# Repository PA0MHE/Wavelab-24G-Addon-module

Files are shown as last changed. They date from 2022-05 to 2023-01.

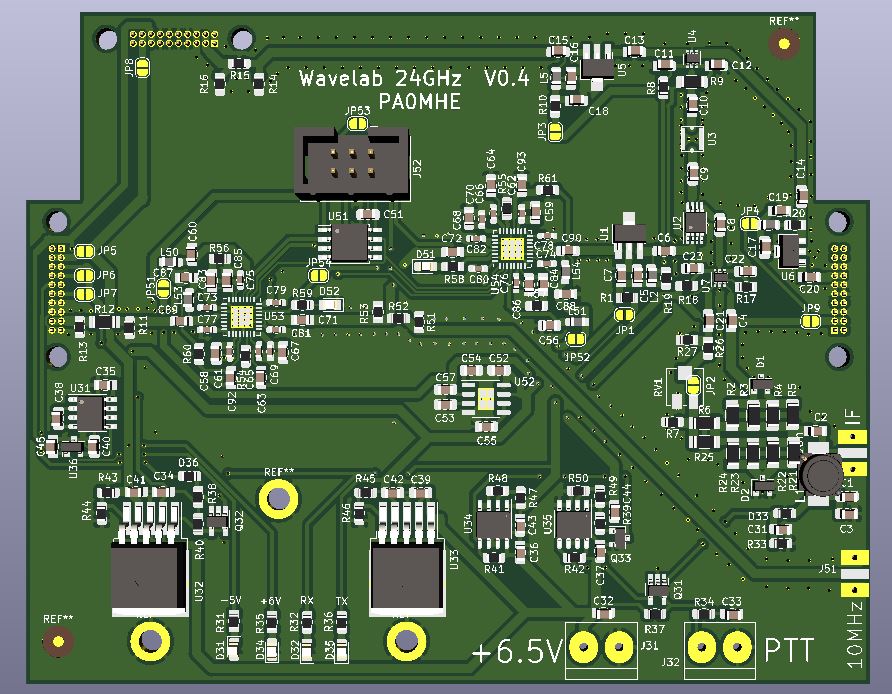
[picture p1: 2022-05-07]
Wavelab24GHzAddon3D_Top_V04.JPG

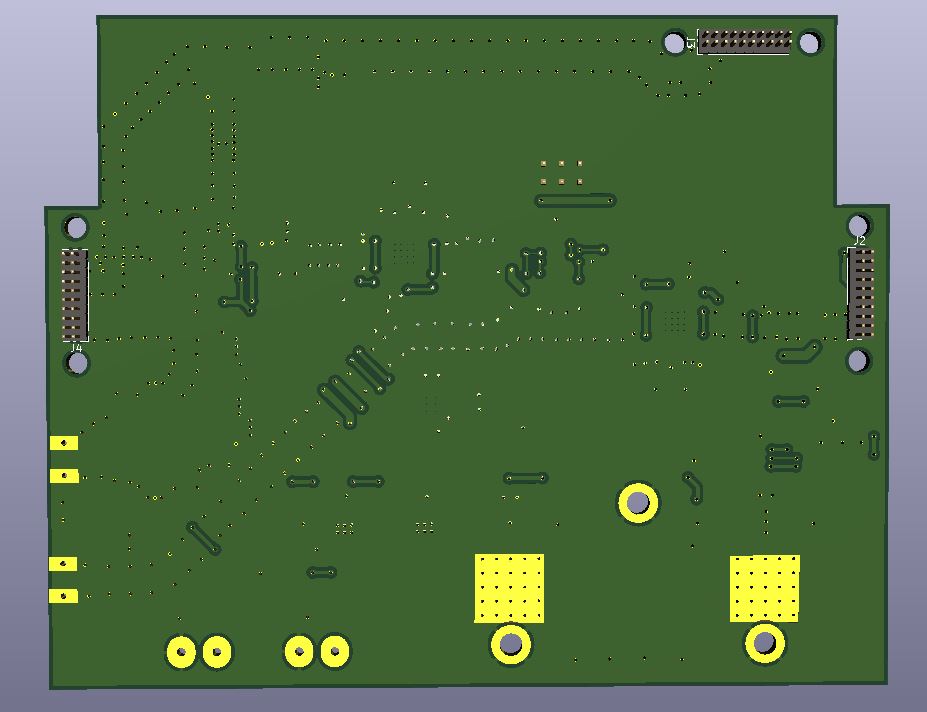
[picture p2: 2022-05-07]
Wavelab24GHzAddon3D_Bottom_v04.JPG

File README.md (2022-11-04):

# Wavelab addon module

Can be used as addon module for the Wavelab 23X1008XP module, which was available during the 2021-2022 timeframe on www.ebay.pl seller:bisonelectronics-sp2jyr
The module converts the first-IF 2364MHz to 432MHz (or 144MHz) , it als generates the required first LO of 1807MHz. It also generates all required DC value, such as 6.5V, +5V, -5V, also the required RX-TX switching is provided. 
The module requires a 10MHz reference signal, it has to be supplied with 7.5V DC. 

# Key components:

HMC213B
2x AS179-92LF
LFB2H2G45SG7C093
2x ADF4351
2x MIC29302
2x BD50HC5MEFJ
ADM7150/1  
ATtiny85-20S  

# PCB

Gerber files are included, PCB's can be ordered at JCL PCB substrate thickness is 0.8mm 

73's Maarten PA0MHE

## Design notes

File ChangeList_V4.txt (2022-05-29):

Complete new PSU circuit
Removed both buck converters --> LDO's MIC29302 and  BD50HC5MEFJ
Input voltage now 6.5V

ATTiny85 U51: connected +3V3A
Pin1 U51 ATTiny85 disconnected from MUXOUT pin30 U54, pin 5 U51 from MUXOUT pin30 U53

Lib element Q31 and Q32 EMG1 changed to TO25-5

Extra 68ohm R19 parallel L2 (drain SBB3089) to avoid oscillations
Footprint both zenerdiode changed to 0805

Add extra 4K7 pullup resistor R37 from PTT to 6.5V
Zener D36 changed to 5V1.
ICSP J52 connector footprint changed to SMD

To get more RX gain, optional U6 PGA103 can be replaced by MGA85675, extra R20 in series drain

Modified IF input can now handle 5W

To improve the -5V stabilization:
- Change the supply voltage from 6.5V into 7.5V. But now a small heatsink is required for U32 and U33
- Change C38 and C40 into 22uF e.g. 22uF 10V 0805 Mouser 81-GRM21BR61A226ME1L

To better get +6V on "+6 TX":
Change R44 from 200E into 180E

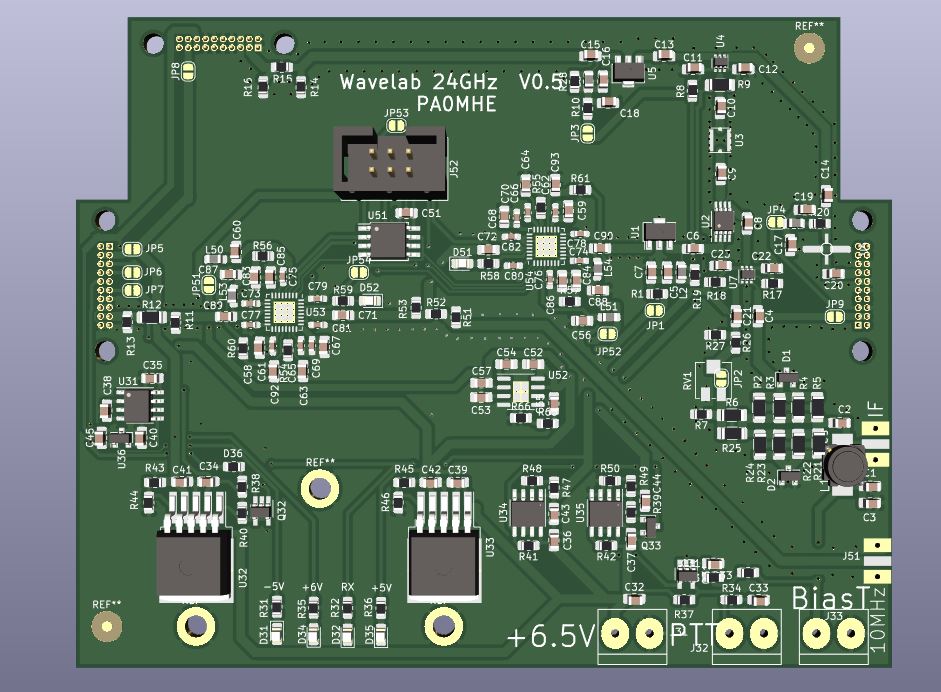
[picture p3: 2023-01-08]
V5_documentation/Wavelab24GHzAddon3D_Top_v05.JPG

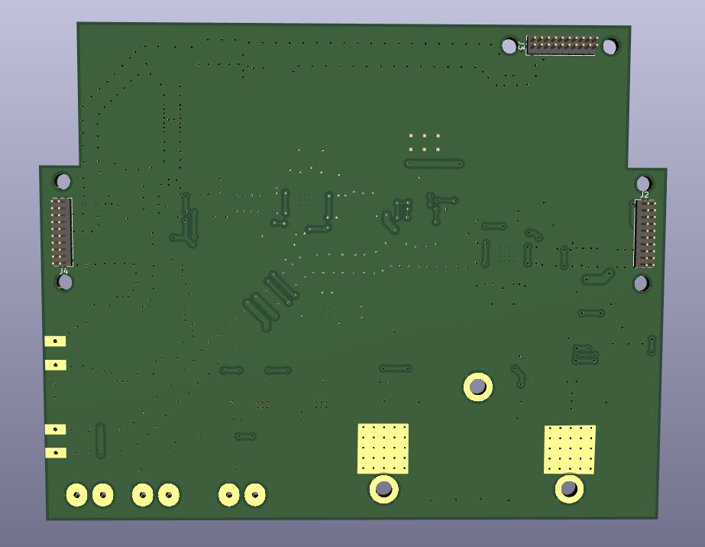
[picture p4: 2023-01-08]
V5_documentation/Wavelab24GHzAddon3D_Bottom_v05.JPG

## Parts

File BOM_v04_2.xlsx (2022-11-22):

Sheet: BOM
Source: | D:\Users\Maarten\Documents\Kicad\WaveLab24GHz\WaveLab24GHz.sch
Date: | 2022-03-28 20:42
Tool: | Eeschema (5.1.7)-1
Component Count: | 200
Ref | Value | Alternative | Footprint | Datasheet | Manufacturer | Vendor
C1 | res 1n |  | Capacitor_SMD:C_0805_2012Metric_Pad1.18x1.45mm_HandSolder | ~
C2 | 220p |  | Capacitor_SMD:C_0805_2012Metric_Pad1.18x1.45mm_HandSolder | ~
C3 | res 220p |  | Capacitor_SMD:C_0805_2012Metric_Pad1.18x1.45mm_HandSolder | ~
C4 | 220p |  | Capacitor_SMD:C_0805_2012Metric_Pad1.18x1.45mm_HandSolder | ~
C5 | 22p |  | Capacitor_SMD:C_0805_2012Metric_Pad1.18x1.45mm_HandSolder | ~
C6 | 1n |  | Capacitor_SMD:C_0805_2012Metric_Pad1.18x1.45mm_HandSolder | ~
C7 | 1nF |  | Capacitor_SMD:C_0805_2012Metric_Pad1.18x1.45mm_HandSolder | ~
C8 | 220p |  | Capacitor_SMD:C_0805_2012Metric_Pad1.18x1.45mm_HandSolder | ~
C9 | 10p |  | Capacitor_SMD:C_0805_2012Metric_Pad1.18x1.45mm_HandSolder | ~
C10 | 10p |  | Capacitor_SMD:C_0805_2012Metric_Pad1.18x1.45mm_HandSolder | ~
C11 | 10p |  | Capacitor_SMD:C_0805_2012Metric_Pad1.18x1.45mm_HandSolder | ~
C12 | 10p |  | Capacitor_SMD:C_0805_2012Metric_Pad1.18x1.45mm_HandSolder | ~
C13 | 10p |  | Capacitor_SMD:C_0805_2012Metric_Pad1.18x1.45mm_HandSolder | ~
C14 | 1n |  | Capacitor_SMD:C_0805_2012Metric_Pad1.18x1.45mm_HandSolder | ~
C15 | 1n |  | Capacitor_SMD:C_0805_2012Metric_Pad1.18x1.45mm_HandSolder | ~
C16 | 10p |  | Capacitor_SMD:C_0805_2012Metric_Pad1.18x1.45mm_HandSolder | ~
C17 | 10p |  | Capacitor_SMD:C_0805_2012Metric_Pad1.18x1.45mm_HandSolder | ~
C18 | 1nF |  | Capacitor_SMD:C_0805_2012Metric_Pad1.18x1.45mm_HandSolder | ~
C19 | 1nF |  | Capacitor_SMD:C_0805_2012Metric_Pad1.18x1.45mm_HandSolder | ~
C20 | 10p |  | Capacitor_SMD:C_0805_2012Metric_Pad1.18x1.45mm_HandSolder | ~
C21 | 220p |  | Capacitor_SMD:C_0805_2012Metric_Pad1.18x1.45mm_HandSolder | ~
C22 | 220p |  | Capacitor_SMD:C_0805_2012Metric_Pad1.18x1.45mm_HandSolder | ~
C23 | 220p |  | Capacitor_SMD:C_0805_2012Metric_Pad1.18x1.45mm_HandSolder | ~
C31 | res |  | Capacitor_SMD:C_0805_2012Metric_Pad1.18x1.45mm_HandSolder | ~
C32 | 100p |  | Capacitor_SMD:C_0805_2012Metric_Pad1.18x1.45mm_HandSolder | ~
C33 | 100p |  | Capacitor_SMD:C_0805_2012Metric_Pad1.18x1.45mm_HandSolder | ~
C34 | 10u |  | Capacitor_SMD:C_0805_2012Metric_Pad1.18x1.45mm_HandSolder | ~
C35 | 10u |  | Capacitor_SMD:C_0805_2012Metric_Pad1.18x1.45mm_HandSolder | ~
C36 | 10u |  | Capacitor_SMD:C_0805_2012Metric_Pad1.18x1.45mm_HandSolder | ~
C37 | 10u |  | Capacitor_SMD:C_0805_2012Metric_Pad1.18x1.45mm_HandSolder | ~
C38 | 10u |  | Capacitor_SMD:C_0805_2012Metric_Pad1.18x1.45mm_HandSolder | ~
C39 | 10u |  | Capacitor_SMD:C_0805_2012Metric_Pad1.18x1.45mm_HandSolder | ~
C40 | 10u |  | Capacitor_SMD:C_0805_2012Metric_Pad1.18x1.45mm_HandSolder | ~
C41 | 10u |  | Capacitor_SMD:C_0805_2012Metric_Pad1.18x1.45mm_HandSolder | ~
C42 | 10u |  | Capacitor_SMD:C_0805_2012Metric_Pad1.18x1.45mm_HandSolder | ~
C43 | 10u |  | Capacitor_SMD:C_0805_2012Metric_Pad1.18x1.45mm_HandSolder | ~
C44 | 10u |  | Capacitor_SMD:C_0805_2012Metric_Pad1.18x1.45mm_HandSolder | ~
C45 | 10u |  | Capacitor_SMD:C_0805_2012Metric_Pad1.18x1.45mm_HandSolder | ~
C51 | 100n |  | Capacitor_SMD:C_0805_2012Metric_Pad1.18x1.45mm_HandSolder | ~
C52 | 10u |  | Capacitor_SMD:C_0805_2012Metric_Pad1.18x1.45mm_HandSolder | ~
C53 | 1u |  | Capacitor_SMD:C_0805_2012Metric_Pad1.18x1.45mm_HandSolder | ~
C54 | 10u |  | Capacitor_SMD:C_0805_2012Metric_Pad1.18x1.45mm_HandSolder | ~
C55 | 1u |  | Capacitor_SMD:C_0805_2012Metric_Pad1.18x1.45mm_HandSolder | ~
C56 | 10u |  | Capacitor_SMD:C_0805_2012Metric_Pad1.18x1.45mm_HandSolder | ~
C57 | 10u |  | Capacitor_SMD:C_0805_2012Metric_Pad1.18x1.45mm_HandSolder | ~
C58 | 100n |  | Capacitor_SMD:C_0805_2012Metric_Pad1.18x1.45mm_HandSolder | ~
C59 | 100n |  | Capacitor_SMD:C_0805_2012Metric_Pad1.18x1.45mm_HandSolder | ~
C60 | 10u |  | Capacitor_SMD:C_0805_2012Metric_Pad1.18x1.45mm_HandSolder | ~
C61 | 10p |  | Capacitor_SMD:C_0603_1608Metric_Pad1.08x0.95mm_HandSolder | ~
C62 | 10p |  | Capacitor_SMD:C_0603_1608Metric_Pad1.08x0.95mm_HandSolder | ~
C63 | 100n |  | Capacitor_SMD:C_0805_2012Metric_Pad1.18x1.45mm_HandSolder | ~
C64 | 100n |  | Capacitor_SMD:C_0805_2012Metric_Pad1.18x1.45mm_HandSolder | ~
C65 | 10p |  | Capacitor_SMD:C_0603_1608Metric_Pad1.08x0.95mm_HandSolder | ~
C66 | 10p |  | Capacitor_SMD:C_0603_1608Metric_Pad1.08x0.95mm_HandSolder | ~
C67 | 100n |  | Capacitor_SMD:C_0805_2012Metric_Pad1.18x1.45mm_HandSolder | ~
C68 | 100n |  | Capacitor_SMD:C_0805_2012Metric_Pad1.18x1.45mm_HandSolder | ~
C69 | 10p |  | Capacitor_SMD:C_0603_1608Metric_Pad1.08x0.95mm_HandSolder | ~
C70 | 10p |  | Capacitor_SMD:C_0603_1608Metric_Pad1.08x0.95mm_HandSolder | ~
C71 | 1n |  | Capacitor_SMD:C_0805_2012Metric_Pad1.18x1.45mm_HandSolder | ~
C72 | 1n |  | Capacitor_SMD:C_0805_2012Metric_Pad1.18x1.45mm_HandSolder | ~
C73 | 100p |  | Capacitor_SMD:C_0603_1608Metric_Pad1.08x0.95mm_HandSolder | ~
C74 | 100p |  | Capacitor_SMD:C_0603_1608Metric_Pad1.08x0.95mm_HandSolder | ~
C75 | 100p |  | Capacitor_SMD:C_0603_1608Metric_Pad1.08x0.95mm_HandSolder | ~
C76 | 100p |  | Capacitor_SMD:C_0603_1608Metric_Pad1.08x0.95mm_HandSolder | ~
C77 | 100p |  | Capacitor_SMD:C_0603_1608Metric_Pad1.08x0.95mm_HandSolder | ~
C78 | 100p |  | Capacitor_SMD:C_0603_1608Metric_Pad1.08x0.95mm_HandSolder | ~
C79 | 100p |  | Capacitor_SMD:C_0603_1608Metric_Pad1.08x0.95mm_HandSolder | ~
C80 | 100p |  | Capacitor_SMD:C_0603_1608Metric_Pad1.08x0.95mm_HandSolder | ~
C81 | 100p |  | Capacitor_SMD:C_0603_1608Metric_Pad1.08x0.95mm_HandSolder | ~
C82 | 100p |  | Capacitor_SMD:C_0603_1608Metric_Pad1.08x0.95mm_HandSolder | ~
C83 | 47n |  | Capacitor_SMD:C_0805_2012Metric_Pad1.18x1.45mm_HandSolder | ~
C84 | 47n |  | Capacitor_SMD:C_0805_2012Metric_Pad1.18x1.45mm_HandSolder | ~
C85 | 3n3 |  | Capacitor_SMD:C_0805_2012Metric_Pad1.18x1.45mm_HandSolder | ~
C86 | 3n3 |  | Capacitor_SMD:C_0805_2012Metric_Pad1.18x1.45mm_HandSolder | ~
C87 | 100p |  | Capacitor_SMD:C_0805_2012Metric_Pad1.18x1.45mm_HandSolder | ~
C88 | 100p |  | Capacitor_SMD:C_0805_2012Metric_Pad1.18x1.45mm_HandSolder | ~
C89 | 22p |  | Capacitor_SMD:C_0805_2012Metric_Pad1.18x1.45mm_HandSolder | ~
C90 | 10p |  | Capacitor_SMD:C_0805_2012Metric_Pad1.18x1.45mm_HandSolder | ~
C92 | 470p |  | Capacitor_SMD:C_0805_2012Metric_Pad1.18x1.45mm_HandSolder | ~
C93 | 470p |  | Capacitor_SMD:C_0805_2012Metric_Pad1.18x1.45mm_HandSolder | ~
D1 | BAV99 |  | Package_TO_SOT_SMD:SOT-23 | https://assets.nexperia.com/documents/data-sheet/BAV99_SER.pdf
D2 | opt |  | Package_TO_SOT_SMD:SOT-23 | https://assets.nexperia.com/documents/data-sheet/BAV99_SER.pdf
D31 | LED |  | LED_SMD:LED_0805_2012Metric_Pad1.15x1.40mm_HandSolder | ~
D32 | LED |  | LED_SMD:LED_0805_2012Metric_Pad1.15x1.40mm_HandSolder | ~
D33 | res |  | Resistor_SMD:R_0805_2012Metric_Pad1.20x1.40mm_HandSolder | ~
D34 | LED |  | LED_SMD:LED_0805_2012Metric_Pad1.15x1.40mm_HandSolder | ~
D35 | LED |  | LED_SMD:LED_0805_2012Metric_Pad1.15x1.40mm_HandSolder | ~
D36 | 5V1 |  | Resistor_SMD:R_0805_2012Metric_Pad1.20x1.40mm_HandSolder | ~
D51 | LED |  | LED_SMD:LED_0805_2012Metric_Pad1.15x1.40mm_HandSolder | ~
D52 | LED |  | LED_SMD:LED_0805_2012Metric_Pad1.15x1.40mm_HandSolder | ~
J1 | Conn_Coaxial |  | my_library:SMA_side_PCB | ~
J2 | Conn_LO |  | my_library:PinHeader_24GHzl | ~
J3 | Conn_TXIF |  | my_library:PinHeader_24GHzl | ~
J4 | Conn_RXIF |  | my_library:PinHeader_24GHzl | ~
J31 | 6.5V |  | my_library:KF301-2P | ~
J32 | PTT |  | my_library:KF301-2P | ~
J33 | Bias-T |  | my_library:KF301-2P | ~
J51 | SMA 10MHz |  | my_library:SMA_side_PCB | ~
J52 | ICSP |  | my_library:IDC-Header_2x03_P2.54mm_SMD | ~
JP1 | S |  | Jumper:SolderJumper-2_P1.3mm_Open_RoundedPad1.0x1.5mm | ~
JP2 | S |  | Jumper:SolderJumper-2_P1.3mm_Open_RoundedPad1.0x1.5mm | ~
JP3 | S |  | Jumper:SolderJumper-2_P1.3mm_Open_RoundedPad1.0x1.5mm | ~
JP4 | S |  | Jumper:SolderJumper-2_P1.3mm_Open_RoundedPad1.0x1.5mm | ~
JP5 | S |  | Jumper:SolderJumper-2_P1.3mm_Open_RoundedPad1.0x1.5mm | ~
JP6 | S |  | Jumper:SolderJumper-2_P1.3mm_Open_RoundedPad1.0x1.5mm | ~
JP7 | S |  | Jumper:SolderJumper-2_P1.3mm_Open_RoundedPad1.0x1.5mm | ~
JP8 | S |  | Jumper:SolderJumper-2_P1.3mm_Open_RoundedPad1.0x1.5mm | ~
JP9 | S |  | Jumper:SolderJumper-2_P1.3mm_Open_RoundedPad1.0x1.5mm | ~
JP51 | S |  | Jumper:SolderJumper-2_P1.3mm_Open_RoundedPad1.0x1.5mm | ~
JP52 | S |  | Jumper:SolderJumper-2_P1.3mm_Open_RoundedPad1.0x1.5mm | ~
JP53 | S |  | Jumper:SolderJumper-2_P1.3mm_Open_RoundedPad1.0x1.5mm | ~
JP54 | S |  | Jumper:SolderJumper-2_P1.3mm_Open_RoundedPad1.0x1.5mm | ~
L1 | res |  | my_library:AirCoilSMD | ~
L2 | 33n |  | Inductor_SMD:L_0805_2012Metric_Pad1.15x1.40mm_HandSolder | ~
L5 | 33n |  | Inductor_SMD:L_0805_2012Metric_Pad1.15x1.40mm_HandSolder | ~
L6 | 33n |  | Inductor_SMD:L_0805_2012Metric_Pad1.15x1.40mm_HandSolder | ~
L50 | 100u |  | Inductor_SMD:L_0805_2012Metric_Pad1.05x1.20mm_HandSolder | ~
L51 | 100u |  | Inductor_SMD:L_0805_2012Metric_Pad1.05x1.20mm_HandSolder | ~
L53 | 3n9 |  | Inductor_SMD:L_0805_2012Metric_Pad1.05x1.20mm_HandSolder | ~
L54 | 3n9 |  | Inductor_SMD:L_0805_2012Metric_Pad1.05x1.20mm_HandSolder | ~
Q31 | FMG1 |  | Package_TO_SOT_SMD:SOT-23-5_HandSoldering
Q32 | FMG1 |  | Package_TO_SOT_SMD:SOT-23-5_HandSoldering
Q33 | BC849 |  | Package_TO_SOT_SMD:SOT-23 | http://www.infineon.com/dgdl/Infineon-BC847SERIES_BC848SERIES_BC849SERIES_BC850SERIES-DS-v01_01-en.pdf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
R1 | 12R |  | Resistor_SMD:R_0805_2012Metric_Pad1.20x1.40mm_HandSolder | ~
R2 | 220R |  | Resistor_SMD:R_1206_3216Metric_Pad1.30x1.75mm_HandSolder | ~
R3 | 220R |  | Resistor_SMD:R_1206_3216Metric_Pad1.30x1.75mm_HandSolder | ~
R4 | 220R |  | Resistor_SMD:R_1206_3216Metric_Pad1.30x1.75mm_HandSolder | ~
R5 | 220R |  | Resistor_SMD:R_1206_3216Metric_Pad1.30x1.75mm_HandSolder | ~
R6 | res |  | Resistor_SMD:R_1206_3216Metric_Pad1.30x1.75mm_HandSolder | ~
R7 | res |  | Resistor_SMD:R_0805_2012Metric_Pad1.20x1.40mm_HandSolder | ~
R8 | 1K |  | Resistor_SMD:R_0805_2012Metric_Pad1.20x1.40mm_HandSolder | ~
R9 | 1K |  | Resistor_SMD:R_1206_3216Metric_Pad1.30x1.75mm_HandSolder | ~
R10 | 12R |  | Resistor_SMD:R_0805_2012Metric_Pad1.20x1.40mm_HandSolder | ~
R11 | res |  | Resistor_SMD:R_0805_2012Metric_Pad1.20x1.40mm_HandSolder | ~
R12 | 0R |  | Resistor_SMD:R_1206_3216Metric_Pad1.30x1.75mm_HandSolder | ~
R13 | res |  | Resistor_SMD:R_0805_2012Metric_Pad1.20x1.40mm_HandSolder | ~
R14 | res |  | Resistor_SMD:R_0805_2012Metric_Pad1.20x1.40mm_HandSolder | ~
R15 | 0R |  | Resistor_SMD:R_0805_2012Metric_Pad1.20x1.40mm_HandSolder | ~
R16 | res |  | Resistor_SMD:R_0805_2012Metric_Pad1.20x1.40mm_HandSolder | ~
R17 | 1K |  | Resistor_SMD:R_0805_2012Metric_Pad1.20x1.40mm_HandSolder | ~
R18 | 1K |  | Resistor_SMD:R_0805_2012Metric_Pad1.20x1.40mm_HandSolder | ~
R19 | 68R |  | Resistor_SMD:R_0805_2012Metric_Pad1.20x1.40mm_HandSolder | ~
R20 | 10R |  | Resistor_SMD:R_0805_2012Metric_Pad1.20x1.40mm_HandSolder | ~
R21 | res |  | Resistor_SMD:R_1206_3216Metric_Pad1.30x1.75mm_HandSolder | ~
R22 | res |  | Resistor_SMD:R_1206_3216Metric_Pad1.30x1.75mm_HandSolder | ~
R23 | res |  | Resistor_SMD:R_1206_3216Metric_Pad1.30x1.75mm_HandSolder | ~
R24 | res |  | Resistor_SMD:R_1206_3216Metric_Pad1.30x1.75mm_HandSolder | ~
R25 | 220R |  | Resistor_SMD:R_1206_3216Metric_Pad1.30x1.75mm_HandSolder | ~
R26 | 0R |  | Resistor_SMD:R_0805_2012Metric_Pad1.20x1.40mm_HandSolder | ~
R27 | 51R |  | Resistor_SMD:R_0805_2012Metric_Pad1.20x1.40mm_HandSolder | ~
R28 | 150R |  | Resistor_SMD:R_0805_2012Metric_Pad1.20x1.40mm_HandSolder | ~
R31 | 2K2 |  | Resistor_SMD:R_0805_2012Metric_Pad1.20x1.40mm_HandSolder | ~
R32 | 2K2 |  | Resistor_SMD:R_0805_2012Metric_Pad1.20x1.40mm_HandSolder | ~
R33 | res |  | Resistor_SMD:R_0805_2012Metric_Pad1.20x1.40mm_HandSolder | ~
R34 | 100R |  | Resistor_SMD:R_0805_2012Metric_Pad1.20x1.40mm_HandSolder | ~
R35 | 2K2 |  | Resistor_SMD:R_0805_2012Metric_Pad1.20x1.40mm_HandSolder | ~
R36 | 2K2 |  | Resistor_SMD:R_0805_2012Metric_Pad1.20x1.40mm_HandSolder | ~
R37 | 4K7 |  | Resistor_SMD:R_0805_2012Metric_Pad1.20x1.40mm_HandSolder | ~
R38 | 47K |  | Resistor_SMD:R_0805_2012Metric_Pad1.20x1.40mm_HandSolder | ~
R39 | 22K |  | Resistor_SMD:R_0805_2012Metric_Pad1.20x1.40mm_HandSolder | ~
R40 | 47K |  | Resistor_SMD:R_0805_2012Metric_Pad1.20x1.40mm_HandSolder | ~
R41 | 47K |  | Resistor_SMD:R_0805_2012Metric_Pad1.20x1.40mm_HandSolder | ~
R42 | 47K |  | Resistor_SMD:R_0805_2012Metric_Pad1.20x1.40mm_HandSolder | ~
R43 | 750R |  | Resistor_SMD:R_0805_2012Metric_Pad1.20x1.40mm_HandSolder | ~
R44 | 200R |  | Resistor_SMD:R_0805_2012Metric_Pad1.20x1.40mm_HandSolder | ~
R45 | 620R |  | Resistor_SMD:R_0805_2012Metric_Pad1.20x1.40mm_HandSolder | ~
R46 | 200R |  | Resistor_SMD:R_0805_2012Metric_Pad1.20x1.40mm_HandSolder | ~
R47 | 0R |  | Resistor_SMD:R_0805_2012Metric_Pad1.20x1.40mm_HandSolder | ~
R48 | res |  | Resistor_SMD:R_0805_2012Metric_Pad1.20x1.40mm_HandSolder | ~
R49 | 0R |  | Resistor_SMD:R_0805_2012Metric_Pad1.20x1.40mm_HandSolder | ~
R50 | res |  | Resistor_SMD:R_0805_2012Metric_Pad1.20x1.40mm_HandSolder | ~
R51 | 62R |  | Resistor_SMD:R_0805_2012Metric_Pad1.20x1.40mm_HandSolder | ~
R52 | 270R |  | Resistor_SMD:R_0805_2012Metric_Pad1.20x1.40mm_HandSolder | ~
R53 | 62R |  | Resistor_SMD:R_0805_2012Metric_Pad1.20x1.40mm_HandSolder | ~
R54 | 5K1 |  | Resistor_SMD:R_0805_2012Metric_Pad1.20x1.40mm_HandSolder | ~
R55 | 5K1 |  | Resistor_SMD:R_0805_2012Metric_Pad1.20x1.40mm_HandSolder | ~
R56 | 470R |  | Resistor_SMD:R_0805_2012Metric_Pad1.20x1.40mm_HandSolder | ~
R57 | 470R |  | Resistor_SMD:R_0805_2012Metric_Pad1.20x1.40mm_HandSolder | ~
R58 | 2K2 |  | Resistor_SMD:R_0805_2012Metric_Pad1.20x1.40mm_HandSolder | ~
R59 | 2K2 |  | Resistor_SMD:R_0805_2012Metric_Pad1.20x1.40mm_HandSolder | ~
R60 | 2K2 |  | Resistor_SMD:R_0805_2012Metric_Pad1.20x1.40mm_HandSolder | ~
R61 | 2K2 |  | Resistor_SMD:R_0805_2012Metric_Pad1.20x1.40mm_HandSolder | ~
RV1 | res |  | Potentiometer_SMD:Potentiometer_Vishay_TS53YJ_Vertical | ~
U1 | SBB3089Z |  | Package_TO_SOT_SMD:SOT-89-3_Handsoldering
U2 | HMC213B |  | Package_SO:MSOP-8_3x3mm_P0.65mm | https://www.analog.com/media/en/technical-documentation/data-sheets/hmc213B.pdf
U3 | LFB2H2G45SG7C093 |  | my_library:LFSN25N
U4 | AS179-92LF | SKY13343-92LF | Package_TO_SOT_SMD:SOT-363_SC-70-6 | http://www.skyworksinc.com/uploads/documents/AS179_92LF_200176H.pdf
U5 | SBB3089Z |  | Package_TO_SOT_SMD:SOT-89-3_Handsoldering
U6 | MGA-86576 |  | Package_TO_SOT_SMD:SOT-89-3 | https://www.minicircuits.com/pdfs/PGA-103+.pdf
U7 | AS179-92LF | SKY13343-92LF | Package_TO_SOT_SMD:SOT-363_SC-70-6 | http://www.skyworksinc.com/uploads/documents/AS179_92LF_200176H.pdf
U31 | ICL7662 |  | Package_SO:SOIC-8_3.9x4.9mm_P1.27mm | http://ww1.microchip.com/downloads/en/DeviceDoc/21469a.pdf
U32 | MIC29302 | LP3876ESX-ADJ | Package_TO_SOT_SMD:TO-263-5_TabPin6
U33 | MIC29302 | LP3876ESX-ADJ | Package_TO_SOT_SMD:TO-263-5_TabPin6
U34 | BD50HC5MEFJ |  | Package_SO:HTSOP-8-1EP_3.9x4.9mm_P1.27mm_EP2.4x3.2mm | http://rohmfs.rohm.com/en/products/databook/datasheet/ic/power/linear_regulator/bdxxga5wefj-e.pdf
U35 | BD50HC5MEFJ |  | Package_SO:HTSOP-8-1EP_3.9x4.9mm_P1.27mm_EP2.4x3.2mm | http://rohmfs.rohm.com/en/products/databook/datasheet/ic/power/linear_regulator/bdxxga5wefj-e.pdf
U36 | TC5950 |  | Package_TO_SOT_SMD:SOT-23
U51 | ATtiny85-20SU |  | Package_SO:SOIJ-8_5.3x5.3mm_P1.27mm | http://ww1.microchip.com/downloads/en/DeviceDoc/atmel-2586-avr-8-bit-microcontroller-attiny25-attiny45-attiny85_datasheet.pdf
U52 | ADM7150DZ-3V3 | ADM7151ARDZ-04-07 | Package_SO:SOIC-8-1EP_3.9x4.9mm_P1.27mm_EP2.29x3mm_ThermalVias
U53 | ADF4351 |  | Package_CSP:LFCSP-32-1EP_5x5mm_P0.5mm_EP3.1x3.1mm_ThermalVias | https://www.analog.com/media/en/technical-documentation/data-sheets/ADF4351.pdf
U54 | ADF4351 |  | Package_CSP:LFCSP-32-1EP_5x5mm_P0.5mm_EP3.1x3.1mm_ThermalVias | https://www.analog.com/media/en/technical-documentation/data-sheets/ADF4351.pdf

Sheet: Bom_grouped
Reference | Quantity | Value | Footprint | Datasheet
C1 | 1 | res 1n | Capacitor_SMD:C_0805_2012Metric_Pad1.18x1.45mm_HandSolder | ~
C9 C10 C11 C12 C13 C16 C17 C20 C90 | 9 | 10p | Capacitor_SMD:C_0805_2012Metric_Pad1.18x1.45mm_HandSolder | ~
C3 | 1 | res 220p | Capacitor_SMD:C_0805_2012Metric_Pad1.18x1.45mm_HandSolder | ~
C31 | 1 | res | Capacitor_SMD:C_0805_2012Metric_Pad1.18x1.45mm_HandSolder | ~
C32 C33 C87 C88 | 4 | 100p | Capacitor_SMD:C_0805_2012Metric_Pad1.18x1.45mm_HandSolder | ~
C34 C35 C36 C37 C38 C39 C40 C41 C42 C43 C44 C45 C52 C54 C56 C57 C60 | 17 | 10u | Capacitor_SMD:C_0805_2012Metric_Pad1.18x1.45mm_HandSolder | ~
C5 C89 | 2 | 22p | Capacitor_SMD:C_0805_2012Metric_Pad1.18x1.45mm_HandSolder | ~
C53 C55 | 2 | 1u | Capacitor_SMD:C_0805_2012Metric_Pad1.18x1.45mm_HandSolder | ~
C51 C58 C59 C63 C64 C67 C68 | 7 | 100n | Capacitor_SMD:C_0805_2012Metric_Pad1.18x1.45mm_HandSolder | ~
C6 C14 C15 C71 C72 | 5 | 1n | Capacitor_SMD:C_0805_2012Metric_Pad1.18x1.45mm_HandSolder | ~
C61 C62 C65 C66 C69 C70 | 6 | 10p | Capacitor_SMD:C_0603_1608Metric_Pad1.08x0.95mm_HandSolder | ~
C7 C18 C19 | 3 | 1nF | Capacitor_SMD:C_0805_2012Metric_Pad1.18x1.45mm_HandSolder | ~
C73 C74 C75 C76 C77 C78 C79 C80 C81 C82 | 10 | 100p | Capacitor_SMD:C_0603_1608Metric_Pad1.08x0.95mm_HandSolder | ~
C2 C4 C8 C21 C22 C23 | 6 | 220p | Capacitor_SMD:C_0805_2012Metric_Pad1.18x1.45mm_HandSolder | ~
C83 C84 | 2 | 47n | Capacitor_SMD:C_0805_2012Metric_Pad1.18x1.45mm_HandSolder | ~
C85 C86 | 2 | 3n3 | Capacitor_SMD:C_0805_2012Metric_Pad1.18x1.45mm_HandSolder | ~
C92 C93 | 2 | 470p | Capacitor_SMD:C_0805_2012Metric_Pad1.18x1.45mm_HandSolder | ~
D1 | 1 | BAV99 | Package_TO_SOT_SMD:SOT-23 | https://assets.nexperia.com/documents/data-sheet/BAV99_SER.pdf
D2 | 1 | opt | Package_TO_SOT_SMD:SOT-23 | https://assets.nexperia.com/documents/data-sheet/BAV99_SER.pdf
D31 D32 D34 D35 D51 D52 | 6 | LED | LED_SMD:LED_0805_2012Metric_Pad1.15x1.40mm_HandSolder | ~
D36 | 1 | 5V1 | Resistor_SMD:R_0805_2012Metric_Pad1.20x1.40mm_HandSolder | ~
J1 | 1 | Conn_Coaxial | my_library:SMA_side_PCB | ~
J2 | 1 | Conn_LO | my_library:PinHeader_24GHzl | ~
J3 | 1 | Conn_TXIF | my_library:PinHeader_24GHzl | ~
J31 | 1 | 6.5V | my_library:KF301-2P | ~
J32 | 1 | PTT | my_library:KF301-2P | ~
J33 | 1 | Bias-T | my_library:KF301-2P | ~
J4 | 1 | Conn_RXIF | my_library:PinHeader_24GHzl | ~
J51 | 1 | SMA 10MHz | my_library:SMA_side_PCB | ~
J52 | 1 | ICSP | my_library:IDC-Header_2x03_P2.54mm_SMD | ~
JP1 JP2 JP3 JP4 JP5 JP6 JP7 JP8 JP9 JP51 JP52 JP53 JP54 | 13 | S | Jumper:SolderJumper-2_P1.3mm_Open_RoundedPad1.0x1.5mm | ~
L1 | 1 | res | my_library:AirCoilSMD | ~
L2 L5 L6 | 3 | 33n | Inductor_SMD:L_0805_2012Metric_Pad1.15x1.40mm_HandSolder | ~
L50 L51 | 2 | 100u | Inductor_SMD:L_0805_2012Metric_Pad1.05x1.20mm_HandSolder | ~
L53 L54 | 2 | 3n9 | Inductor_SMD:L_0805_2012Metric_Pad1.05x1.20mm_HandSolder | ~
Q31 Q32 | 2 | FMG1 | Package_TO_SOT_SMD:SOT-23-5_HandSoldering
Q33 | 1 | BC849 | Package_TO_SOT_SMD:SOT-23 | http://www.infineon.com/dgdl/Infineon-BC847SERIES_BC848SERIES_BC849SERIES_BC850SERIES-DS-v01_01-en.pdf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
R1 R10 | 2 | 12R | Resistor_SMD:R_0805_2012Metric_Pad1.20x1.40mm_HandSolder | ~
R7 R11 R13 R14 R16 R33 D33 R48 R50 | 9 | res | Resistor_SMD:R_0805_2012Metric_Pad1.20x1.40mm_HandSolder | ~
R12 | 1 | 0R | Resistor_SMD:R_1206_3216Metric_Pad1.30x1.75mm_HandSolder | ~
R15 R26 R47 R49 | 4 | 0R | Resistor_SMD:R_0805_2012Metric_Pad1.20x1.40mm_HandSolder | ~
R19 | 1 | 68R | Resistor_SMD:R_0805_2012Metric_Pad1.20x1.40mm_HandSolder | ~
R20 | 1 | 10R | Resistor_SMD:R_0805_2012Metric_Pad1.20x1.40mm_HandSolder | ~
R6 R21 R22 R23 R24 | 5 | res | Resistor_SMD:R_1206_3216Metric_Pad1.30x1.75mm_HandSolder | ~
R2 R3 R4 R5 R25 | 5 | 220R | Resistor_SMD:R_1206_3216Metric_Pad1.30x1.75mm_HandSolder | ~
R27 | 1 | 51R | Resistor_SMD:R_0805_2012Metric_Pad1.20x1.40mm_HandSolder | ~
R28 | 1 | 150R | Resistor_SMD:R_0805_2012Metric_Pad1.20x1.40mm_HandSolder | ~
R31 R32 R35 R36 R58 R59 R60 R61 | 8 | 2K2 | Resistor_SMD:R_0805_2012Metric_Pad1.20x1.40mm_HandSolder | ~
R34 | 1 | 100R | Resistor_SMD:R_0805_2012Metric_Pad1.20x1.40mm_HandSolder | ~
R37 | 1 | 4K7 | Resistor_SMD:R_0805_2012Metric_Pad1.20x1.40mm_HandSolder | ~
R39 | 1 | 22K | Resistor_SMD:R_0805_2012Metric_Pad1.20x1.40mm_HandSolder | ~
R38 R40 R41 R42 | 4 | 47K | Resistor_SMD:R_0805_2012Metric_Pad1.20x1.40mm_HandSolder | ~
R43 | 1 | 750R | Resistor_SMD:R_0805_2012Metric_Pad1.20x1.40mm_HandSolder | ~
R44 R46 | 2 | 200R | Resistor_SMD:R_0805_2012Metric_Pad1.20x1.40mm_HandSolder | ~
R45 | 1 | 620R | Resistor_SMD:R_0805_2012Metric_Pad1.20x1.40mm_HandSolder | ~
R51 R53 | 2 | 62R | Resistor_SMD:R_0805_2012Metric_Pad1.20x1.40mm_HandSolder | ~
R52 | 1 | 270R | Resistor_SMD:R_0805_2012Metric_Pad1.20x1.40mm_HandSolder | ~
R54 R55 | 2 | 5K1 | Resistor_SMD:R_0805_2012Metric_Pad1.20x1.40mm_HandSolder | ~
R56 R57 | 2 | 470R | Resistor_SMD:R_0805_2012Metric_Pad1.20x1.40mm_HandSolder | ~
R8 R17 R18 | 3 | 1K | Resistor_SMD:R_0805_2012Metric_Pad1.20x1.40mm_HandSolder | ~
R9 | 1 | 1K | Resistor_SMD:R_1206_3216Metric_Pad1.30x1.75mm_HandSolder | ~
RV1 | 1 | res | Potentiometer_SMD:Potentiometer_Vishay_TS53YJ_Vertical | ~
U1 U5 | 2 | SBB3089Z | Package_TO_SOT_SMD:SOT-89-3_Handsoldering
U2 | 1 | HMC213B | Package_SO:MSOP-8_3x3mm_P0.65mm | https://www.analog.com/media/en/technical-documentation/data-sheets/hmc213B.pdf
U3 | 1 | LFB2H2G45SG7C093 | my_library:LFSN25N
U31 | 1 | ICL7662 | Package_SO:SOIC-8_3.9x4.9mm_P1.27mm | http://ww1.microchip.com/downloads/en/DeviceDoc/21469a.pdf
U32 U33 | 2 | MIC29302 | Package_TO_SOT_SMD:TO-263-5_TabPin6
U34 U35 | 2 | BD50HC5MEFJ | Package_SO:HTSOP-8-1EP_3.9x4.9mm_P1.27mm_EP2.4x3.2mm | http://rohmfs.rohm.com/en/products/databook/datasheet/ic/power/linear_regulator/bdxxga5wefj-e.pdf
U36 | 1 | TC5950 | Package_TO_SOT_SMD:SOT-23
U4 U7 | 2 | AS179-92LF | Package_TO_SOT_SMD:SOT-363_SC-70-6 | http://www.skyworksinc.com/uploads/documents/AS179_92LF_200176H.pdf
U51 | 1 | ATtiny85-20SU | Package_SO:SOIJ-8_5.3x5.3mm_P1.27mm | http://ww1.microchip.com/downloads/en/DeviceDoc/atmel-2586-avr-8-bit-microcontroller-attiny25-attiny45-attiny85_datasheet.pdf
U52 | 1 | ADM7150DZ-3V3 | Package_SO:SOIC-8-1EP_3.9x4.9mm_P1.27mm_EP2.29x3mm_ThermalVias
U53 U54 | 2 | ADF4351 | Package_CSP:LFCSP-32-1EP_5x5mm_P0.5mm_EP3.1x3.1mm_ThermalVias | https://www.analog.com/media/en/technical-documentation/data-sheets/ADF4351.pdf
U6 | 1 | MGA-86576 | Package_TO_SOT_SMD:SOT-89-3 | https://www.minicircuits.com/pdfs/PGA-103+.pdf

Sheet: BOM_cost
Qty | Reference(s) | Value |  |  |  | Alternatives
7 | C1, C6, C14, C15, C31, C71, C72 | 1n
7 | C2, C3, C4, C8, C21, C22, C23 | 220p
2 | C5, C89 | 22p
3 | C7, C18, C19 | 1nF
9 | C9, C10, C11, C12, C13, C16, C17, C20, C90 | 10p
4 | C32, C33, C87, C88 | 100p
17 | C34, C35, C36, C37, C38, C39, C40, C41, C42, C43, C44, C45, C52, C54, C56, C57, C60 | 10u | 963-LMR212BD7106KG-T | 0.15 | 2.55
7 | C51, C58, C59, C63, C64, C67, C68 | 100n
2 | C53, C55 | 1u
6 | C61, C62, C65, C66, C69, C70 | 10p | 581-06035A100C4T2A
10 | C73, C74, C75, C76, C77, C78, C79, C80, C81, C82 | 100p | 581-06035A101K
2 | C83, C84 | 47n
2 | C85, C86 | 3n3
2 | C92, C93 | 470p
63 | Rest capacitor |  |  | 0.05 | 3.15
2 | D1, D2 | BAV99 | 621-BAV99WQ-7-F | 0.24 | 0.48
6 | D31, D32, D34, D35, D51, D52 | LED | APTD2012LQBC | 0.5 | 3
1 | D33 | 18V | 78-BZX584C18 | 0.24 | 0.24
1 | D36 | 5V1 | 821-BZY55B5V1RBG | 0.24 | 0.24
2 | J1, J51 | SMA_side | Ebay
3 | J2,J3,J4 | Pinstrip | 649-221111-00020T4LF | 0.98 | 2.94
1 | J31 | 6.5V
1 | J32 | PTT
1 | J33 | Bias-T
1 | J51 | SMA 10MHz
1 | L1 | 500n
3 | L2, L5, L6 | L
2 | L50, L51 | 100u
2 | L53, L54 | 3n9
2 | Q31, Q32 | FMG1 | 755-FMG1AT148 | 0.4 | 0.8
1 | Q33 | BC849 |  | 0.15 | 0.15
2 | R1, R10 | 12R
10 | R2, R3, R4, R5, R6, R21, R22, R23, R24, R25 | 470R | 667-ERJ-P14J471U | 0.09 | 0.9
2 | R7, R19 | 68R
5 | R8, R17, R18, R47, R49 | 1K
1 | R9 | 1K
4 | R11, R13, R14, R16 | res
1 | R12 | 0R
2 | R15, R20 | 0R
1 | R26 | 220R
1 | R27 | 75R
8 | R31, R32, R35, R36, R58, R59, R60, R61 | 2K2
1 | R33 | 5K6
1 | R34 | 100R
1 | R37 | 4K7
4 | R38, R40, R41, R42 | 47K
1 | R39 | 22K
1 | R43 | 750R
2 | R44, R46 | 200R
1 | R45 | 620R
2 | R48, R50 | 180R
2 | R51, R53 | 62R
1 | R52 | 270R
2 | R54, R55 | 5K1
2 | R56, R57 | 470R
1 | RV1 | 100R
23 | Rest resistor SMD 0805 |  |  | 0.05 | 1.15
2 | U1, U5 | SBB3089Z | 772-TQP369182 | 2.71 | 5.42
1 | U2 | HMC213B | 584-HMC213BMS8ETR | 14.99 | 14.99
1 | U3 | LFB2H2G45SG7C093 | 81-LFB2H2G45SG7A159 | 0.26 | 0.26
2 | U4, U7 | AS179-92LF | 873-SKY13343-92LF | 1.44 | 2.88 | 873-SKY13343-92LF
1 | U6 | PGA-103+ | 139-PGA-103 | 3.21 | 3.21
1 | U31 | ICL7662 | 700-ICL7662CBAT | 4.06 | 4.06
2 | U32, U33 | MIC29302 | 998-MIC29302AWDTR | 2.11 | 4.22 | LP3876ESXADJNOPB
2 | U34, U35 | BD50HC5MEFJ | 755-BD50HC5MEFJ-ME2 | 0.86 | 1.72
1 | U36 | TC5950 | 579-TC595002ECBTR | 0.95 | 0.95
1 | U51 | ATtiny85-20SU | 556-ATTINY85-20SU | 1.18 | 1.18
1 | U52 | ADM7150DZ-3V3 | 584-ADM7150ARDZ3.3R7 | 8.04 | 8.04 | ADM7151_ARDZ-07-R7 (slight PCB mod required)
2 | U53, U54 | ADF4351 | 584-ADF4351BCPZ-R7 | 16.78 | 33.56
 |  |  |  |  | 96.09

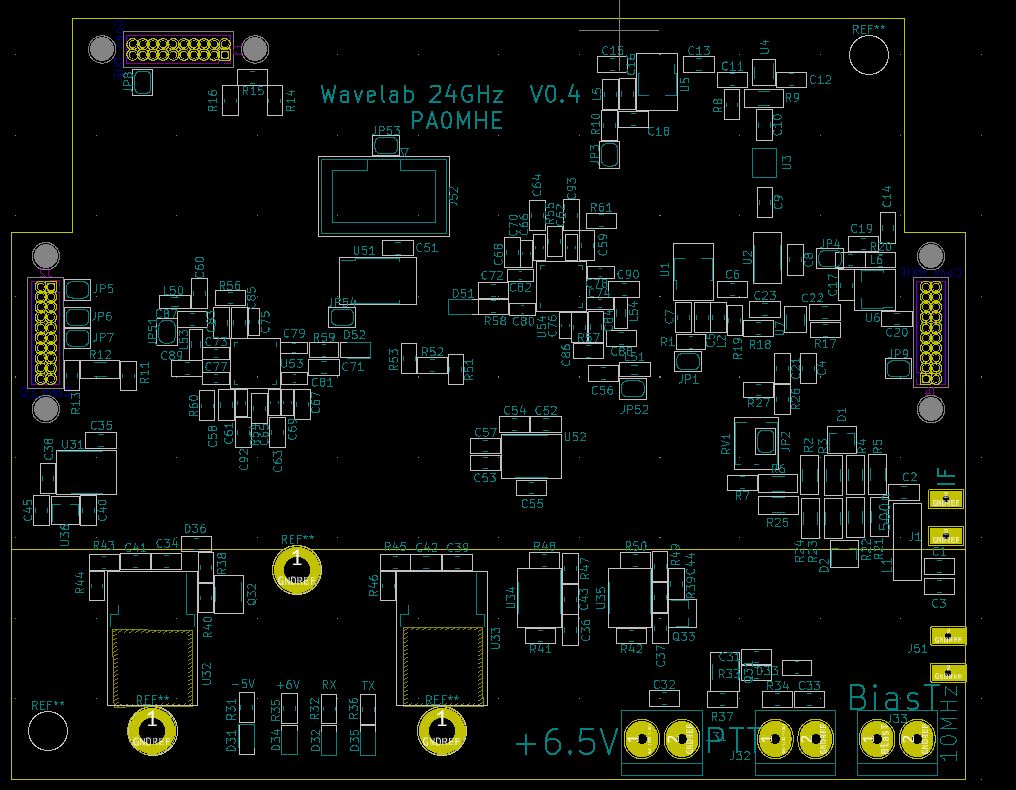
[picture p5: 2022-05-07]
Wavelab24GHzAddon3D_Component_V04.JPG

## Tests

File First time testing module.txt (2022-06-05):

How I did a first time test and measured a new Wavelab 24GHz add-on module.

I use a step by step approach:
- The pinstrips J2, J3 and J4 I only mount afterwards.
- Optically check if everything is present and well soldered.

Supply:
In RX, PTT open, high on pin 1 J32
-  +5V on C42
-  +5V on C43
- +3V3 on C57
-  -5V on C45
in TX mode, PTT short to ground, and pin 9 and 10 of J2 temporarily short circuited to simulate the RF module .
-  +6V on C41
-  +5V on C44

PTT switching:
In RX:
C12 and C22: 0V
C11 and C23: 5V
In TX:
C12 and C22: 5V
C11 and C23: 0V

In circuit programming U51:
Or directly upload HEX files or compile and upload.
Arduino IDE setting for compiling: Board "ATtiny25/45/85", Processor "ATtiny85", Clock "internal 1MHz"
Connect AVRISP MKII to J52
Ensure both U53 and U54 are powered: JP51 and JP52 closed.
Leave JP53 and JP54 always open

Test ADF4351's U53 and U54:
- Test with a multimeter in ohms if U53 and U54 are soldered correctly: 
    - Open pins: With a multimeter in the diode range, the plus terminal to ground and the other to a connected component: e.g. C or R you can measure if the pin is connected. Example: on C64 and C66,connected to pin 23 U54, you should measure ~~0.2V. 
- Check also short circuits: e.g. no short circuit between pin 23 C64 and  pin 24 C68. 
- Measure currents of U53 and U54 on JP51 and JP52, if OK short both jumpers JP51 and JP52 you can expect 71mA no code loaded 88mA code loaded
- with a DC voltmeter I usually check all DC values on all pins of U53 and U54, tapping on connected components. But perhaps this step is only needed to find fault.
- Ensure U51 is programmed
- Ensure 10MHz reference is connected and arrives at inputs of U53 and U54
- Connect supply; after 1 second first lock indication should switch on 500ms later also the other.
- 1807MHz should be present at pin 17-18 J2
- Check U1: connect a current meter between pins 1 and 2 from JP1: you should expect a current of ~~ 55 mA, if OK short JP1
- 1932MHz (case IF 432MHz) should be present on C6

Test 2364MHz TX:
Place module in TX, PTT short to ground
- Check U5: connect a current meter between pins 1 and 2 from JP3: you should expect a current of ~~ 55 mA, if OK short JP3
- 2364MHz should be present on pin 3-4 J3 (As test stimulus I usually connect +2dBm 432MHz on C8, and measure +1dBm on 2364MHz)

Test RX:
Place module in RX, PTT open
- Check U6: connect a current meter between pins 1 and 2 from JP4: you should expect a current of ~~ 15 mA (case MGA-86576), if OK short JP3-  
- As test stumulus I insert -20dBm 2364MHz (e.g. from a Pluto) on pin 13-14 J4 and I measure RX gain ~4dB 432MHz on J1

Add-on module current consumption:
- RX mode: ~~300mA
- TX mode: ~~335mA

Finally I mount the pinstrips and mate with the RF module.
Then step by step I verify the currents via the solder jumpers and close them.

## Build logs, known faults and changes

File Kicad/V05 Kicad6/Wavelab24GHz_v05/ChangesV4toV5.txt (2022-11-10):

R65, R66 added as option for U52 ADM7151 (chip shortage)
R36      update service print to "+5V"
U6       changed footprint to MGA-86576 (still possible to mount PGA103+, but too little gain)
J31, J32, J33, J1, J2, J3 No solder paste

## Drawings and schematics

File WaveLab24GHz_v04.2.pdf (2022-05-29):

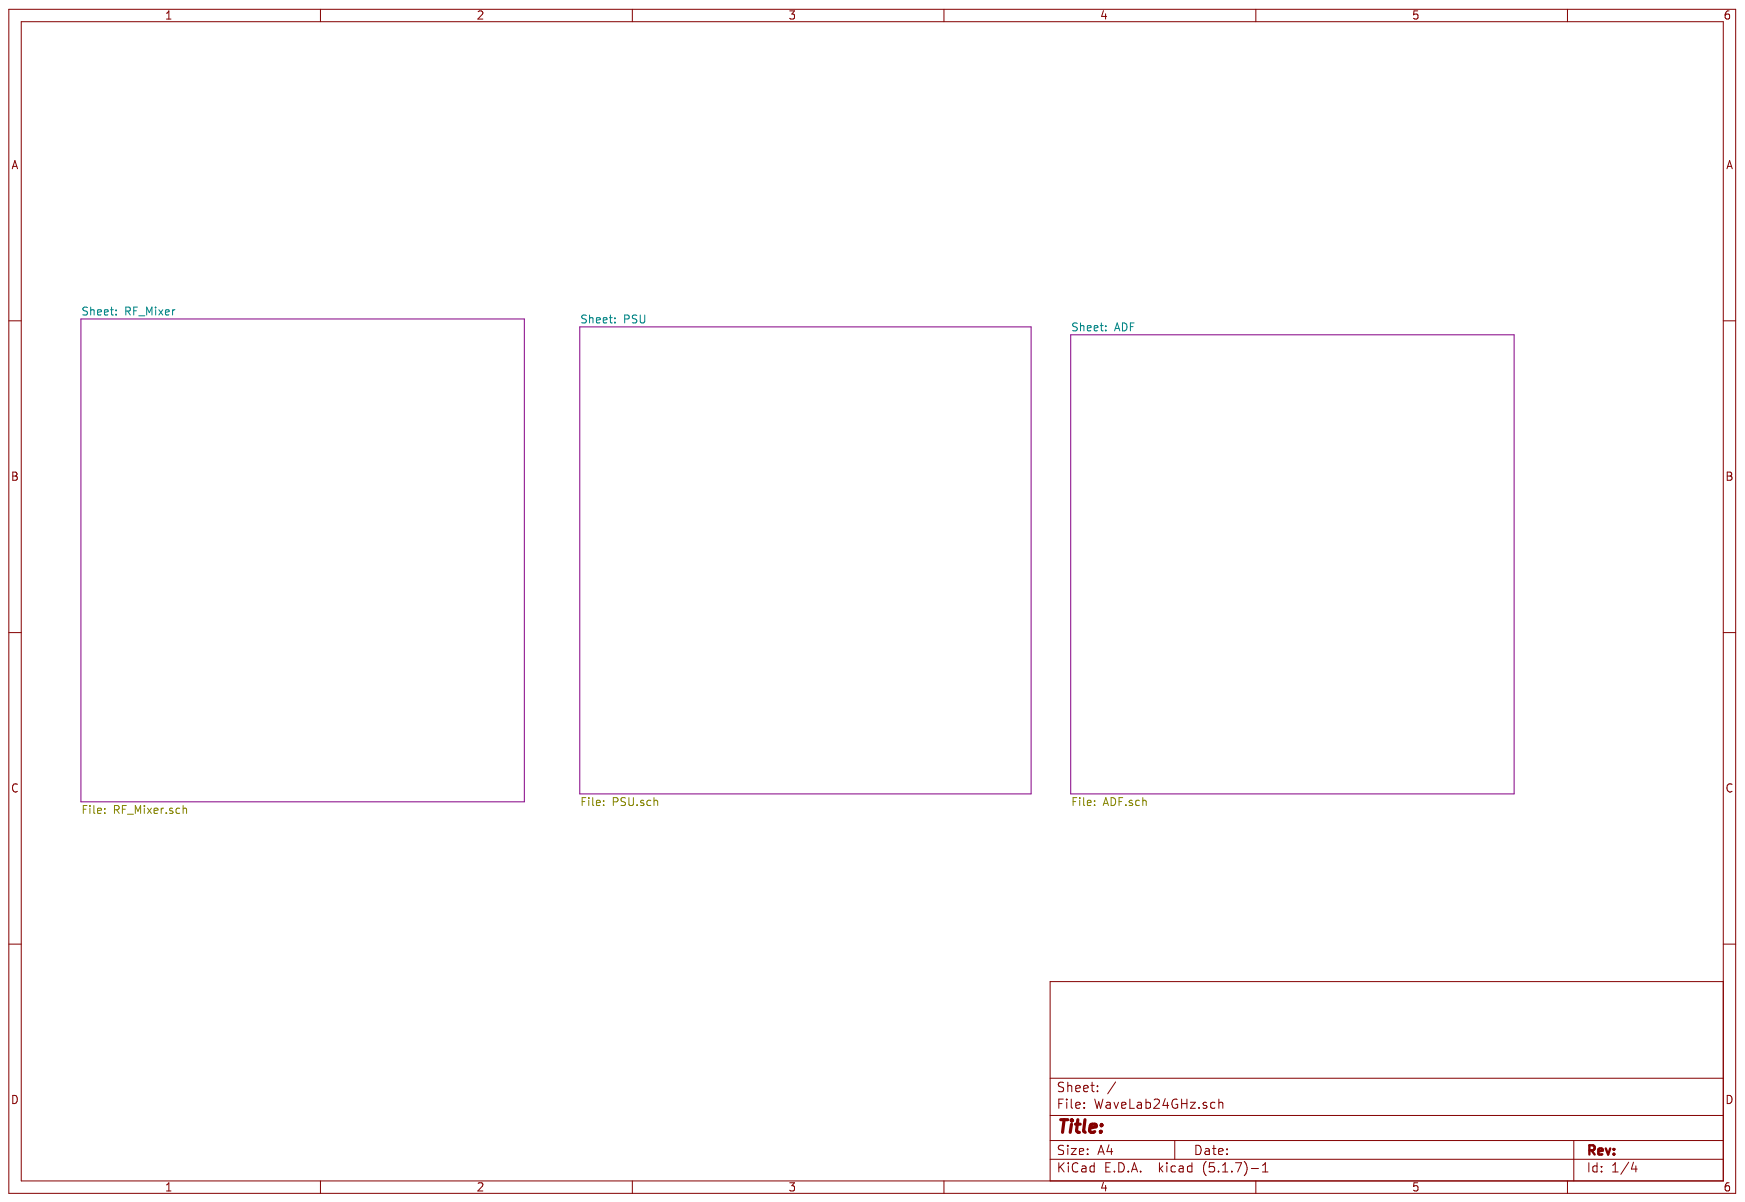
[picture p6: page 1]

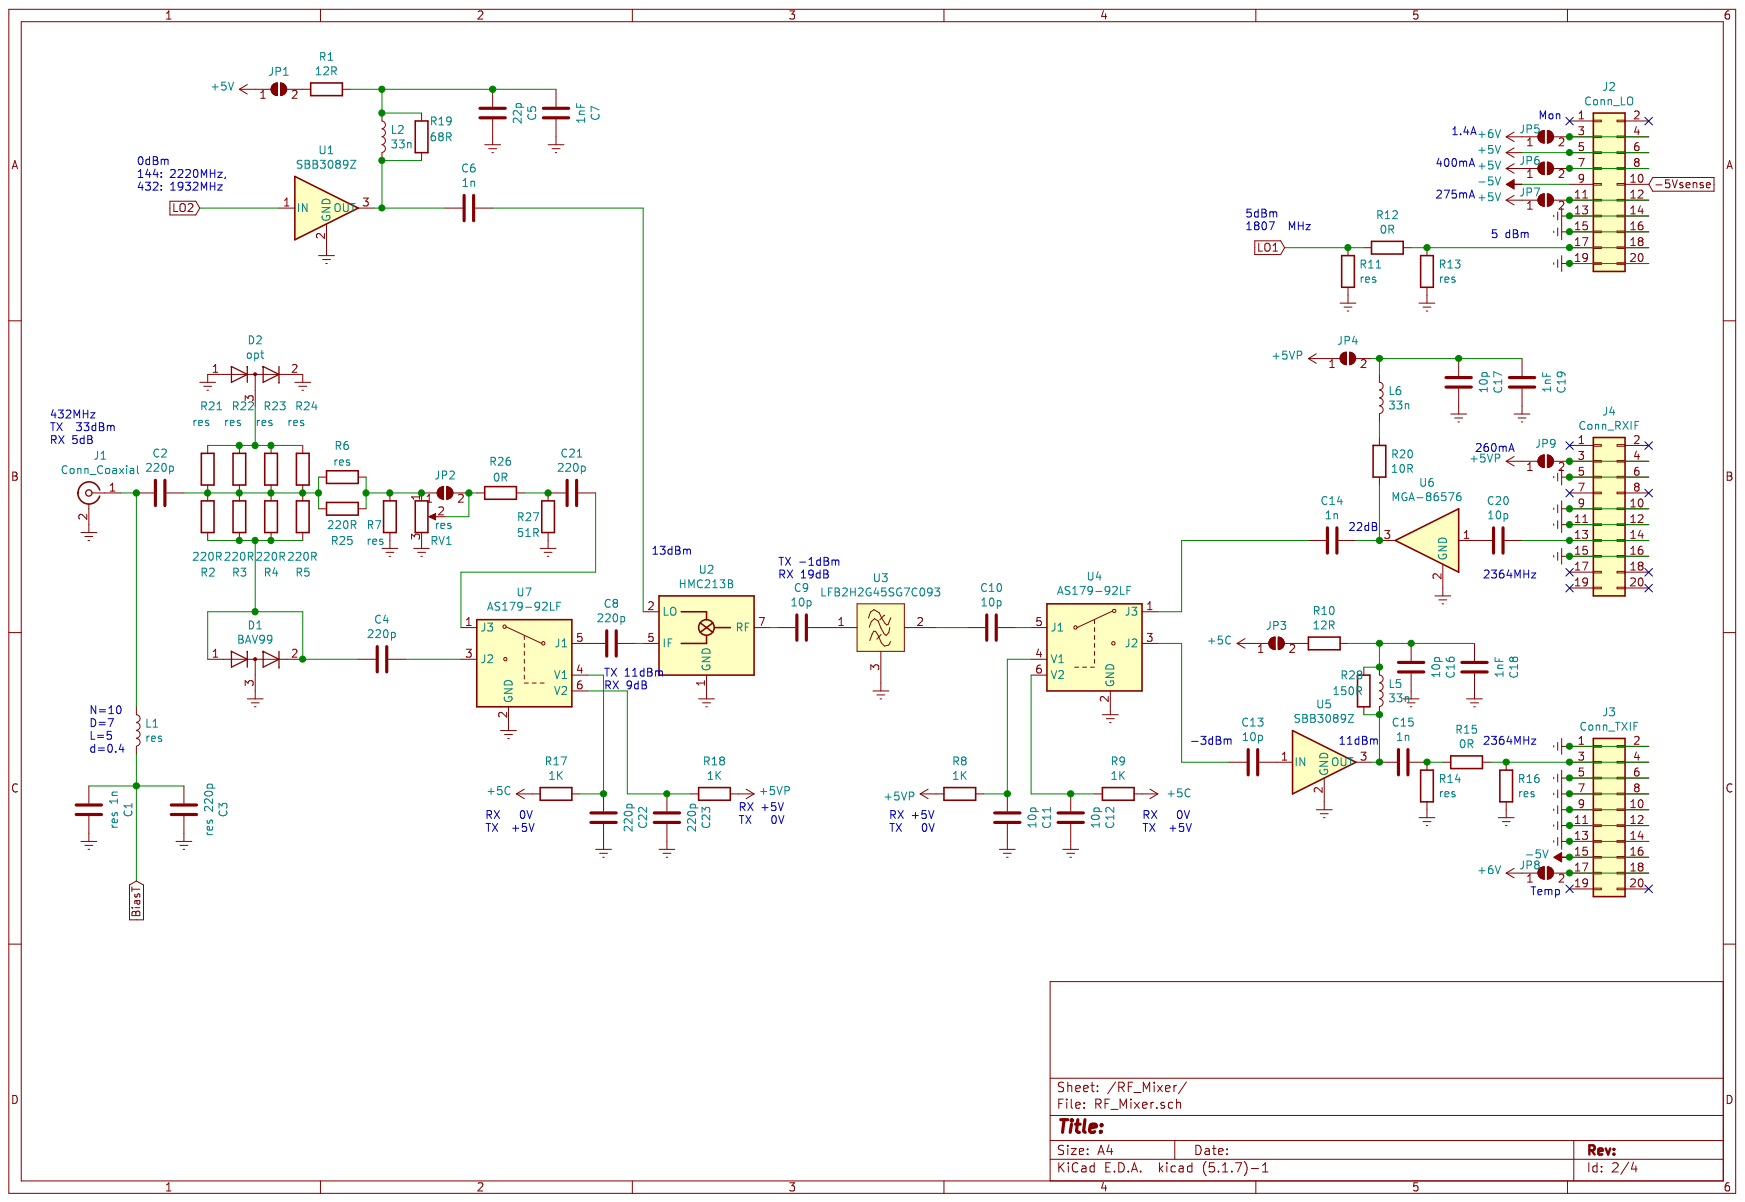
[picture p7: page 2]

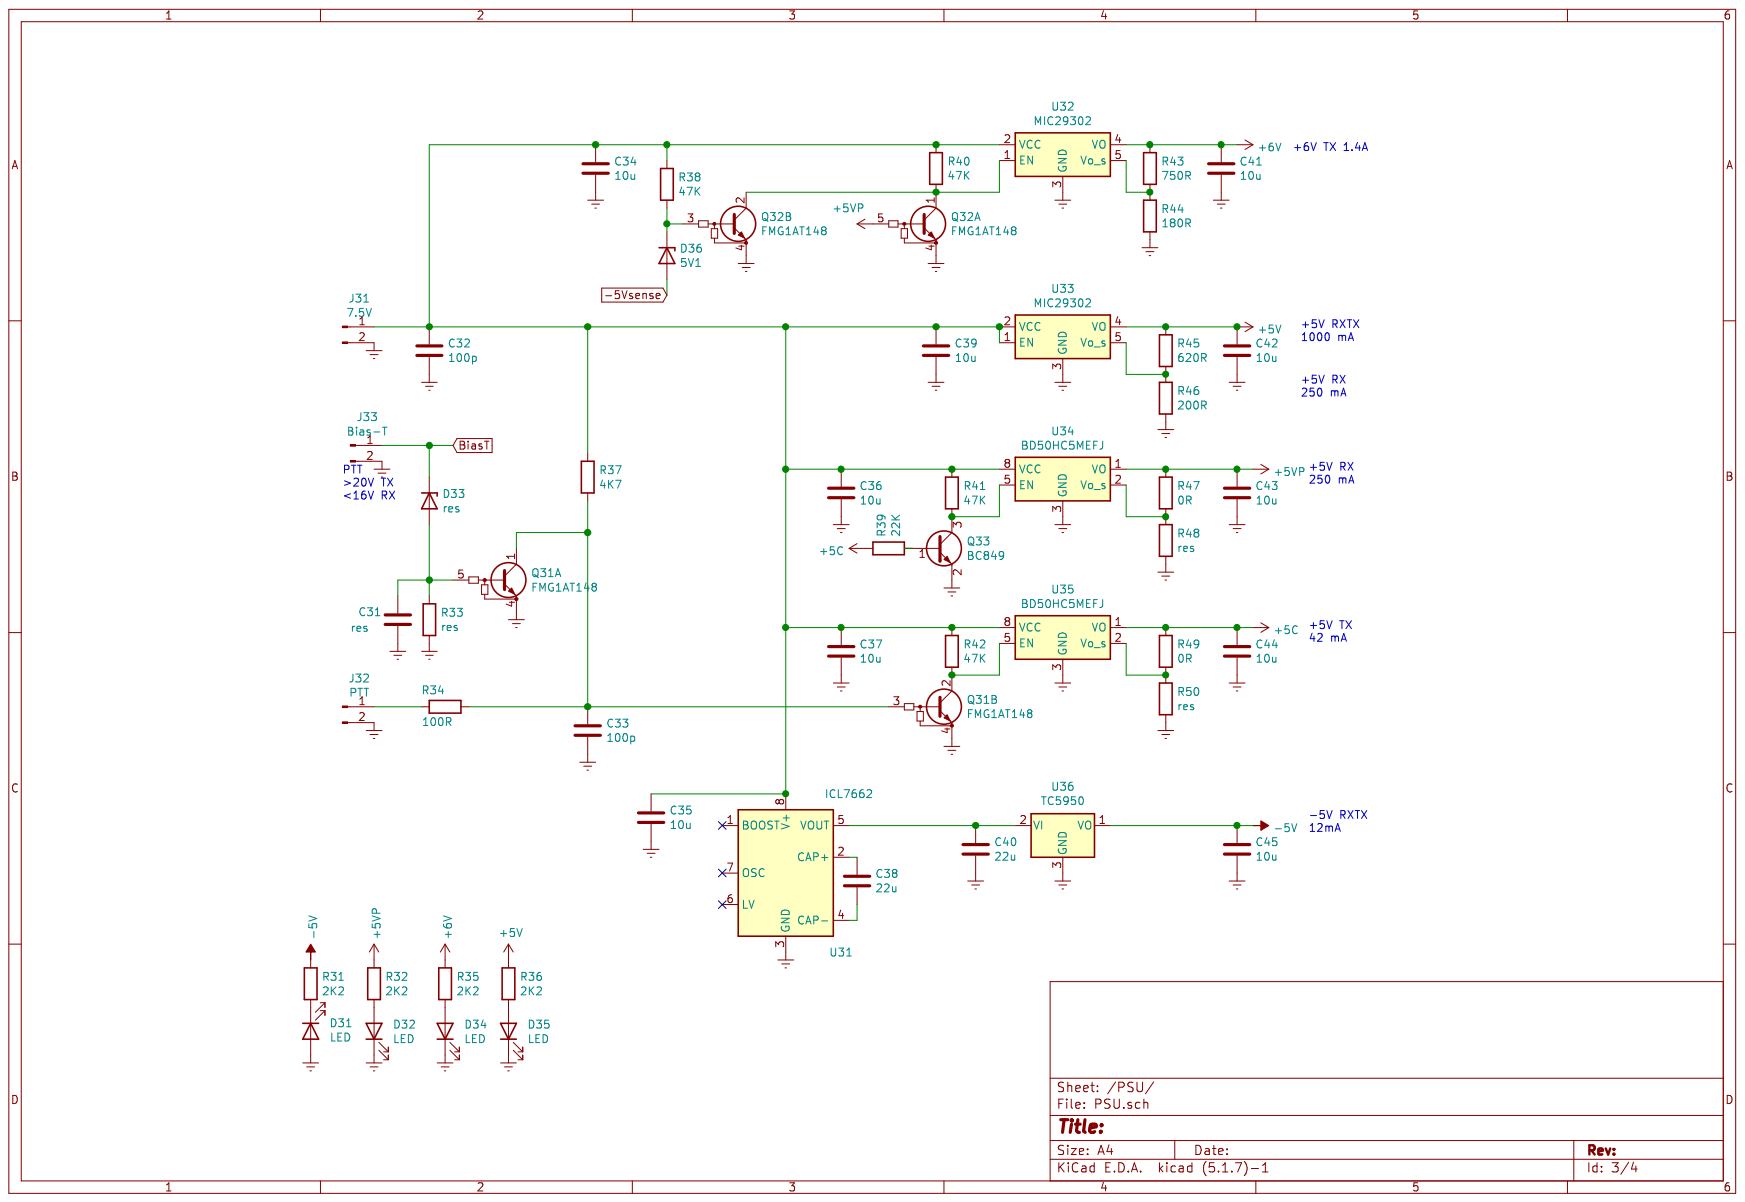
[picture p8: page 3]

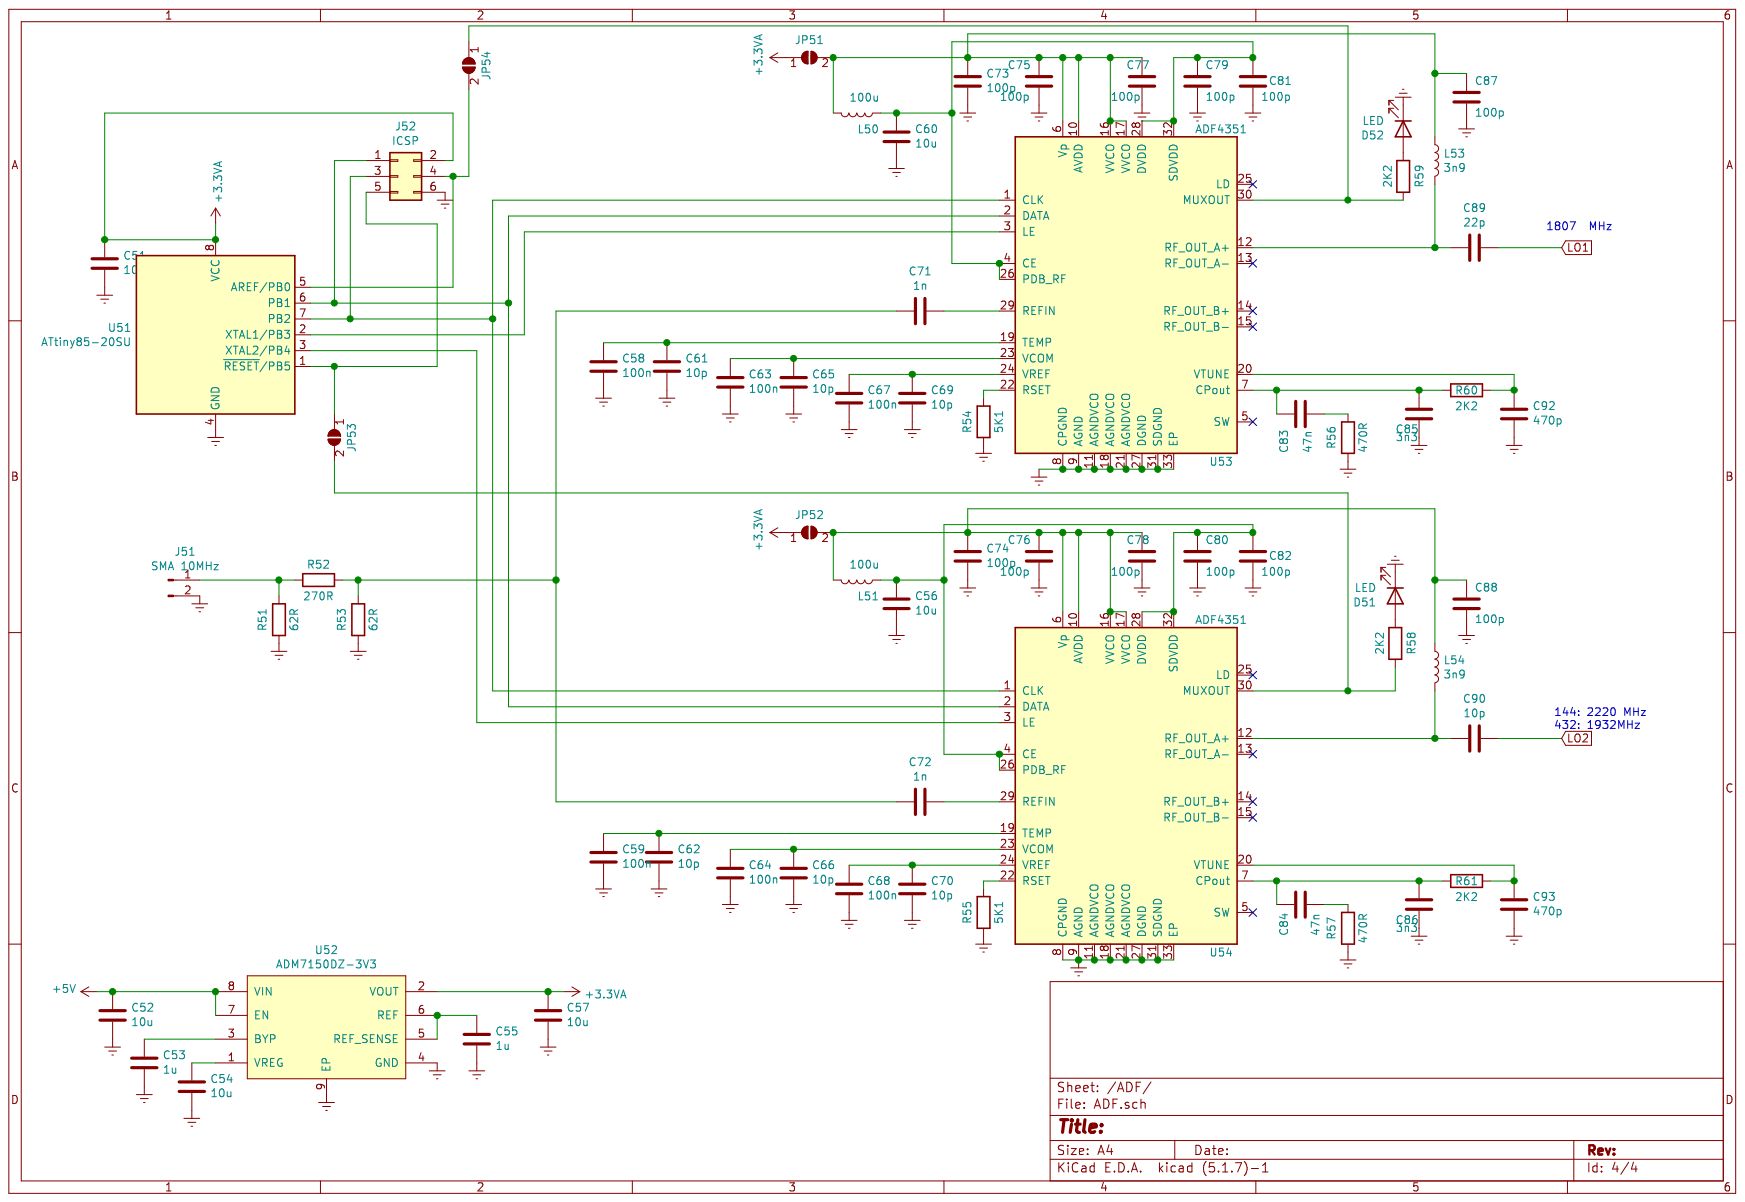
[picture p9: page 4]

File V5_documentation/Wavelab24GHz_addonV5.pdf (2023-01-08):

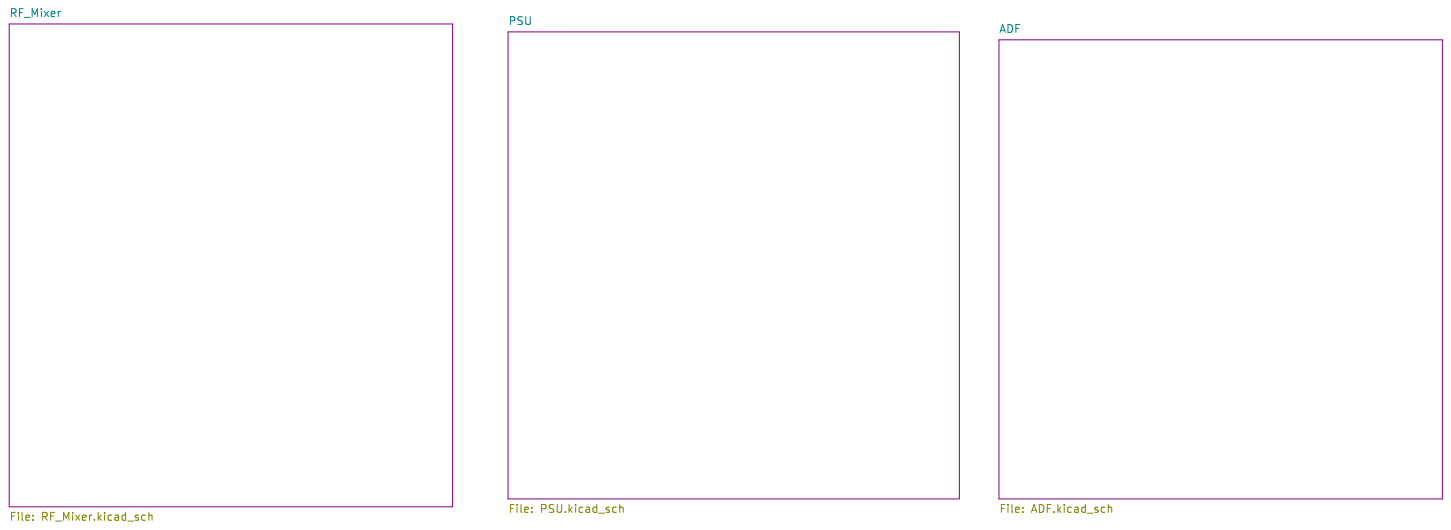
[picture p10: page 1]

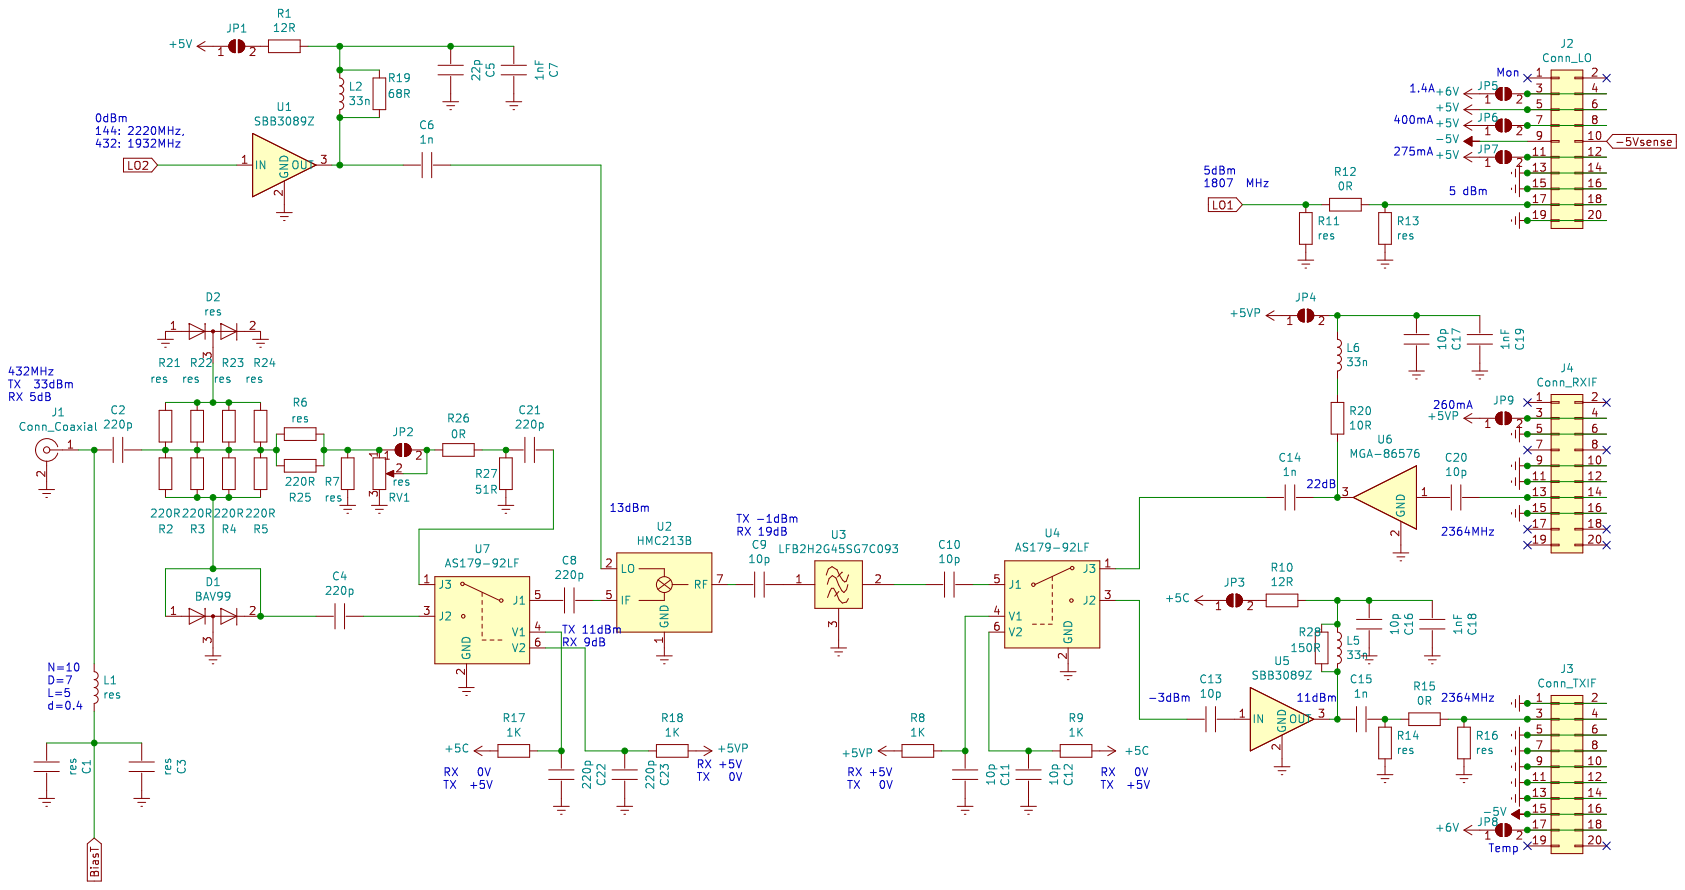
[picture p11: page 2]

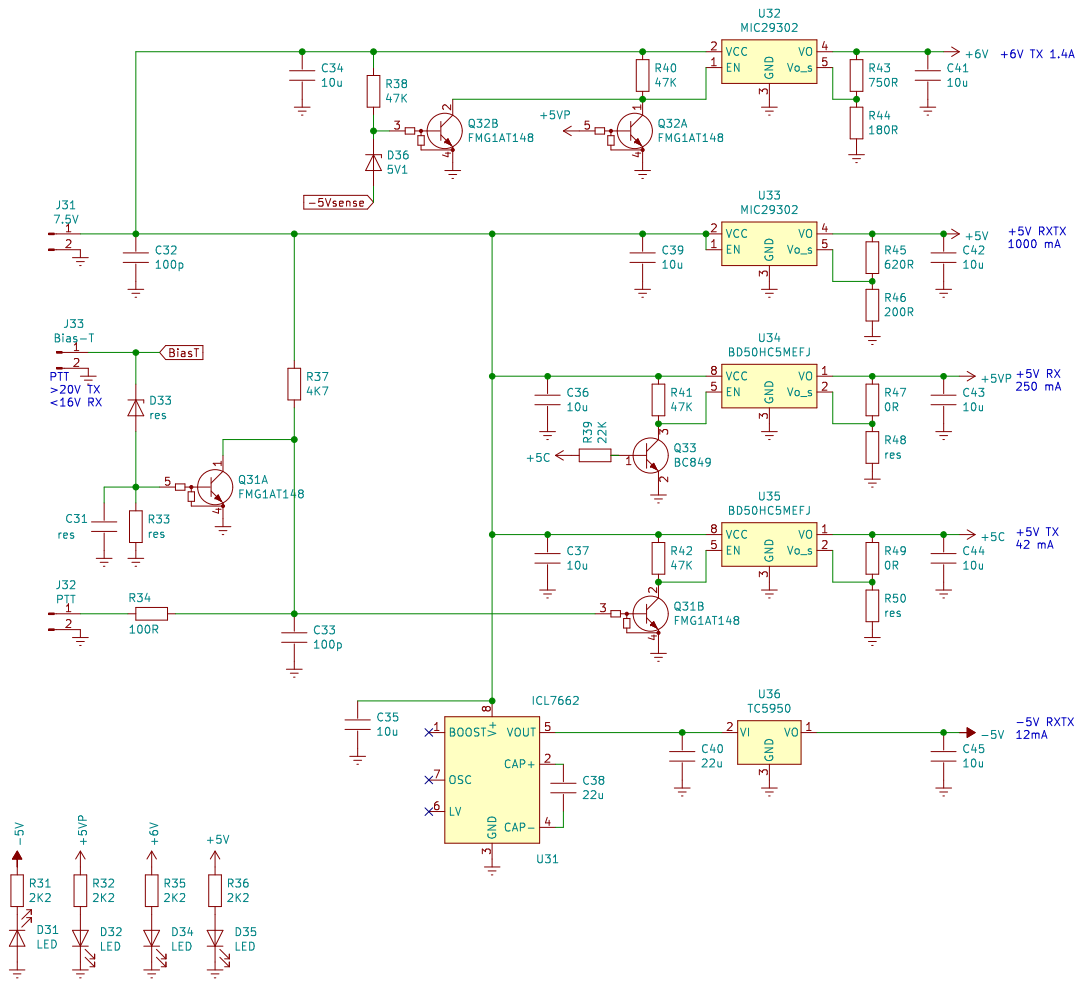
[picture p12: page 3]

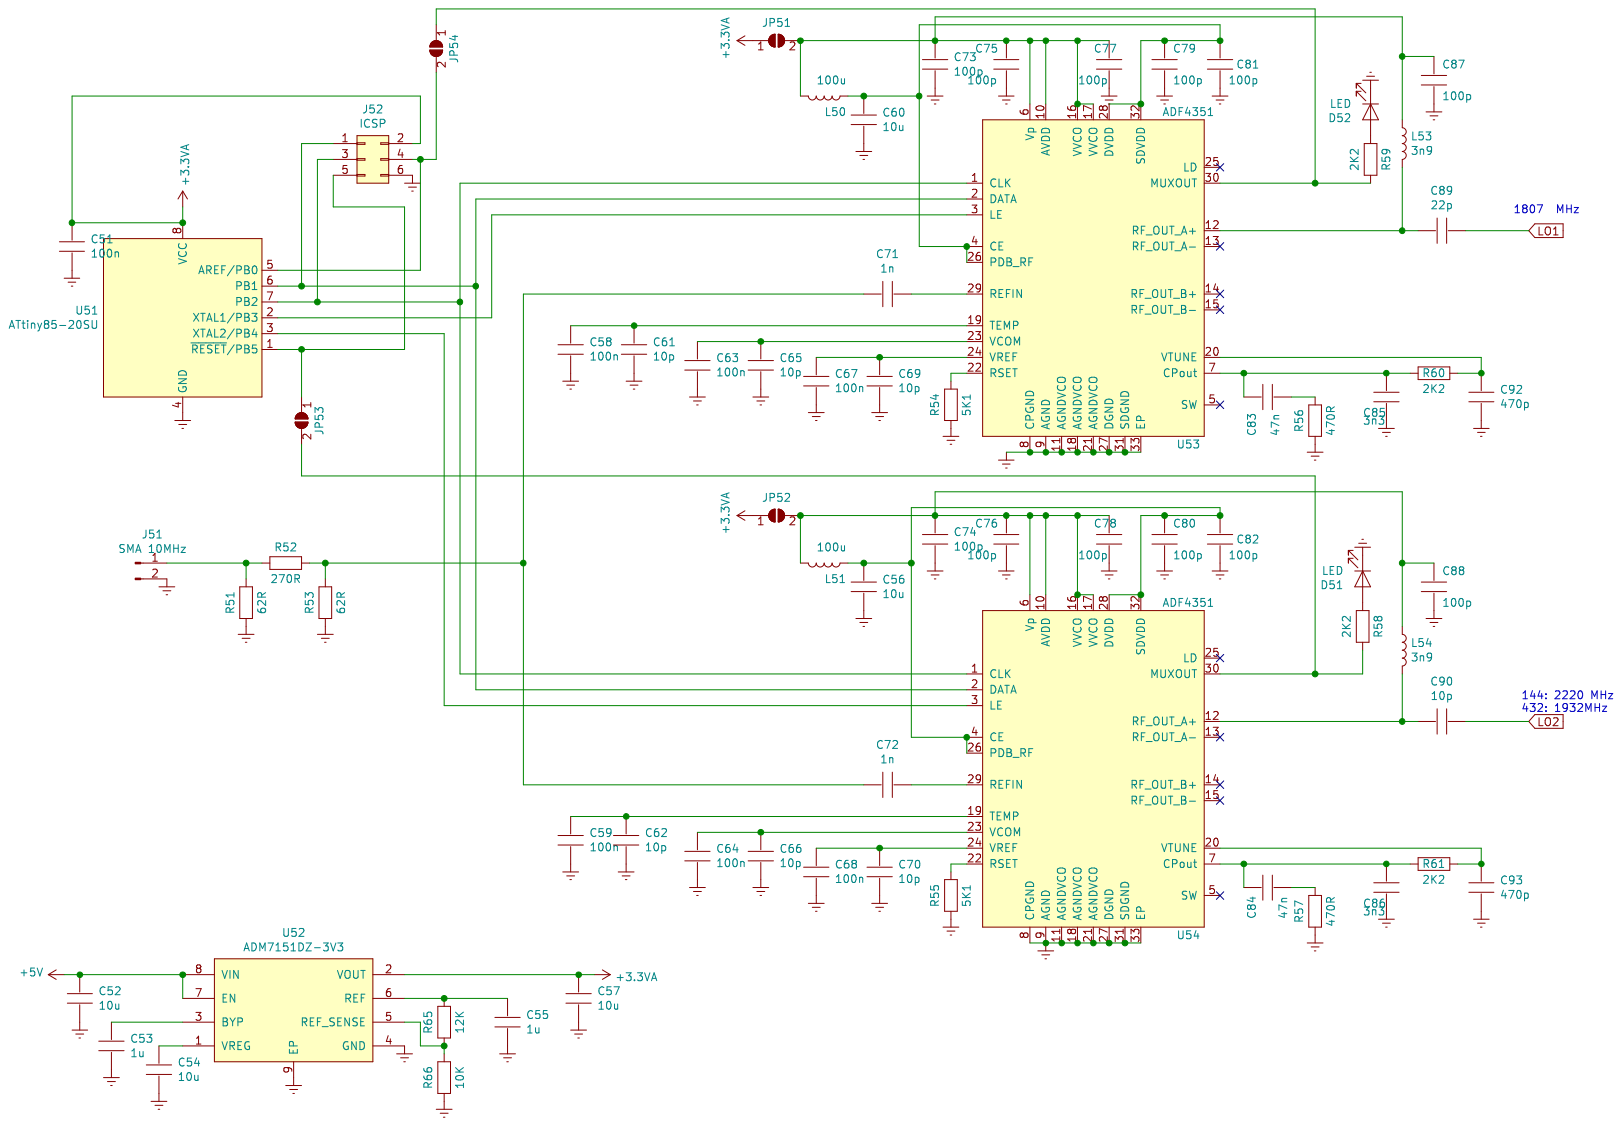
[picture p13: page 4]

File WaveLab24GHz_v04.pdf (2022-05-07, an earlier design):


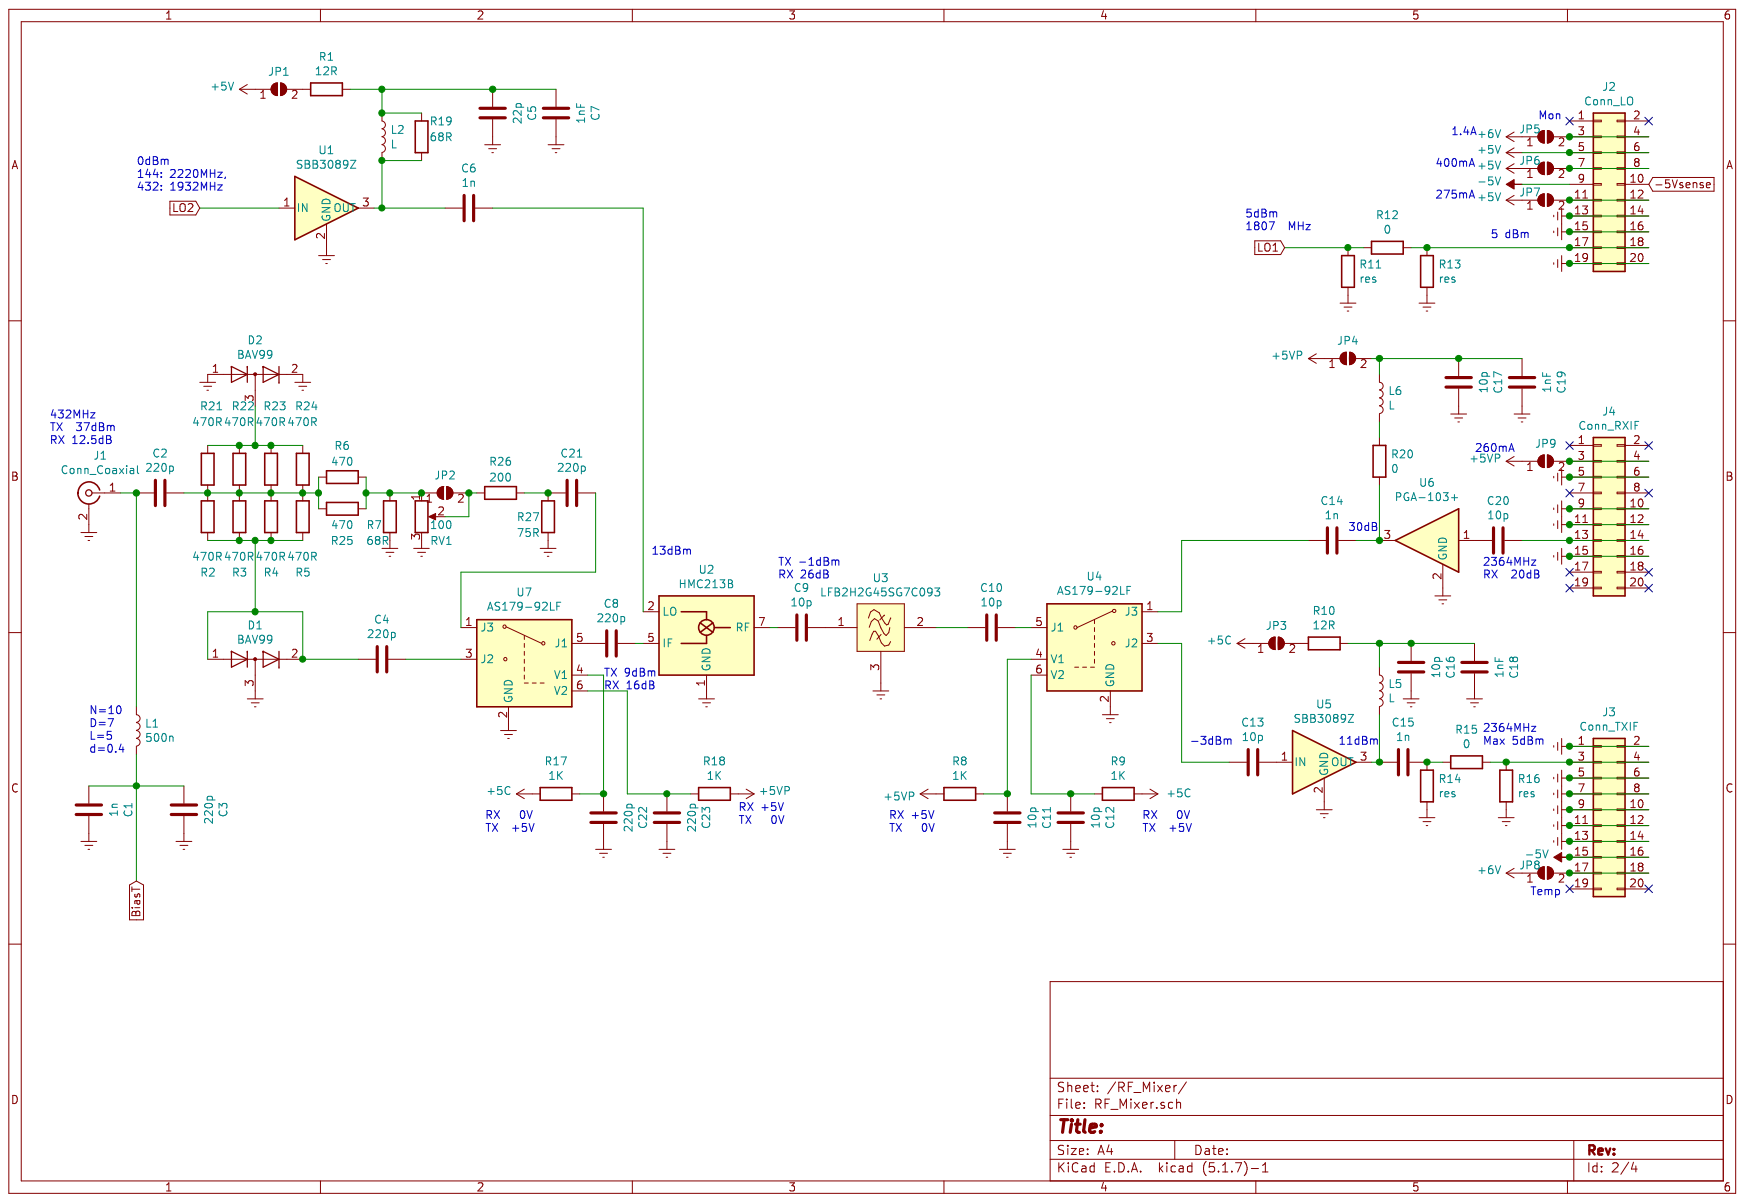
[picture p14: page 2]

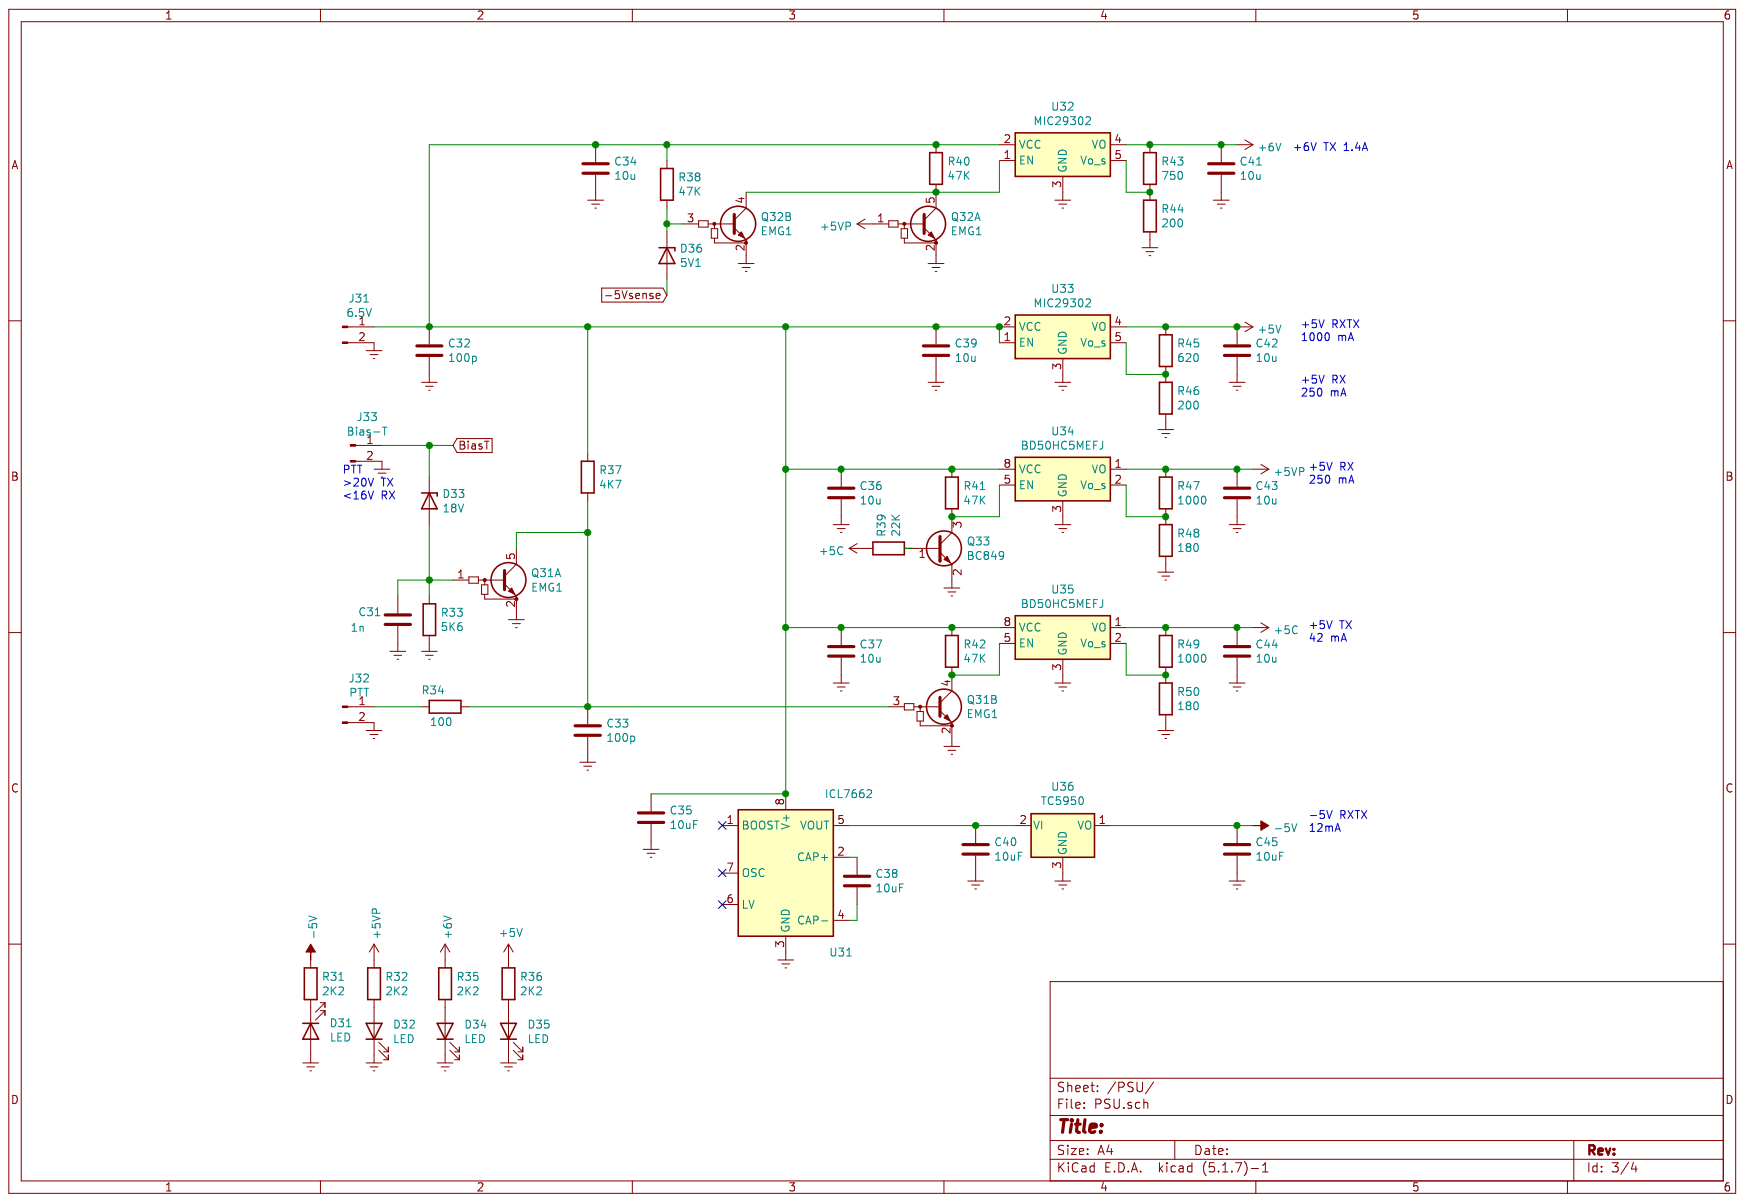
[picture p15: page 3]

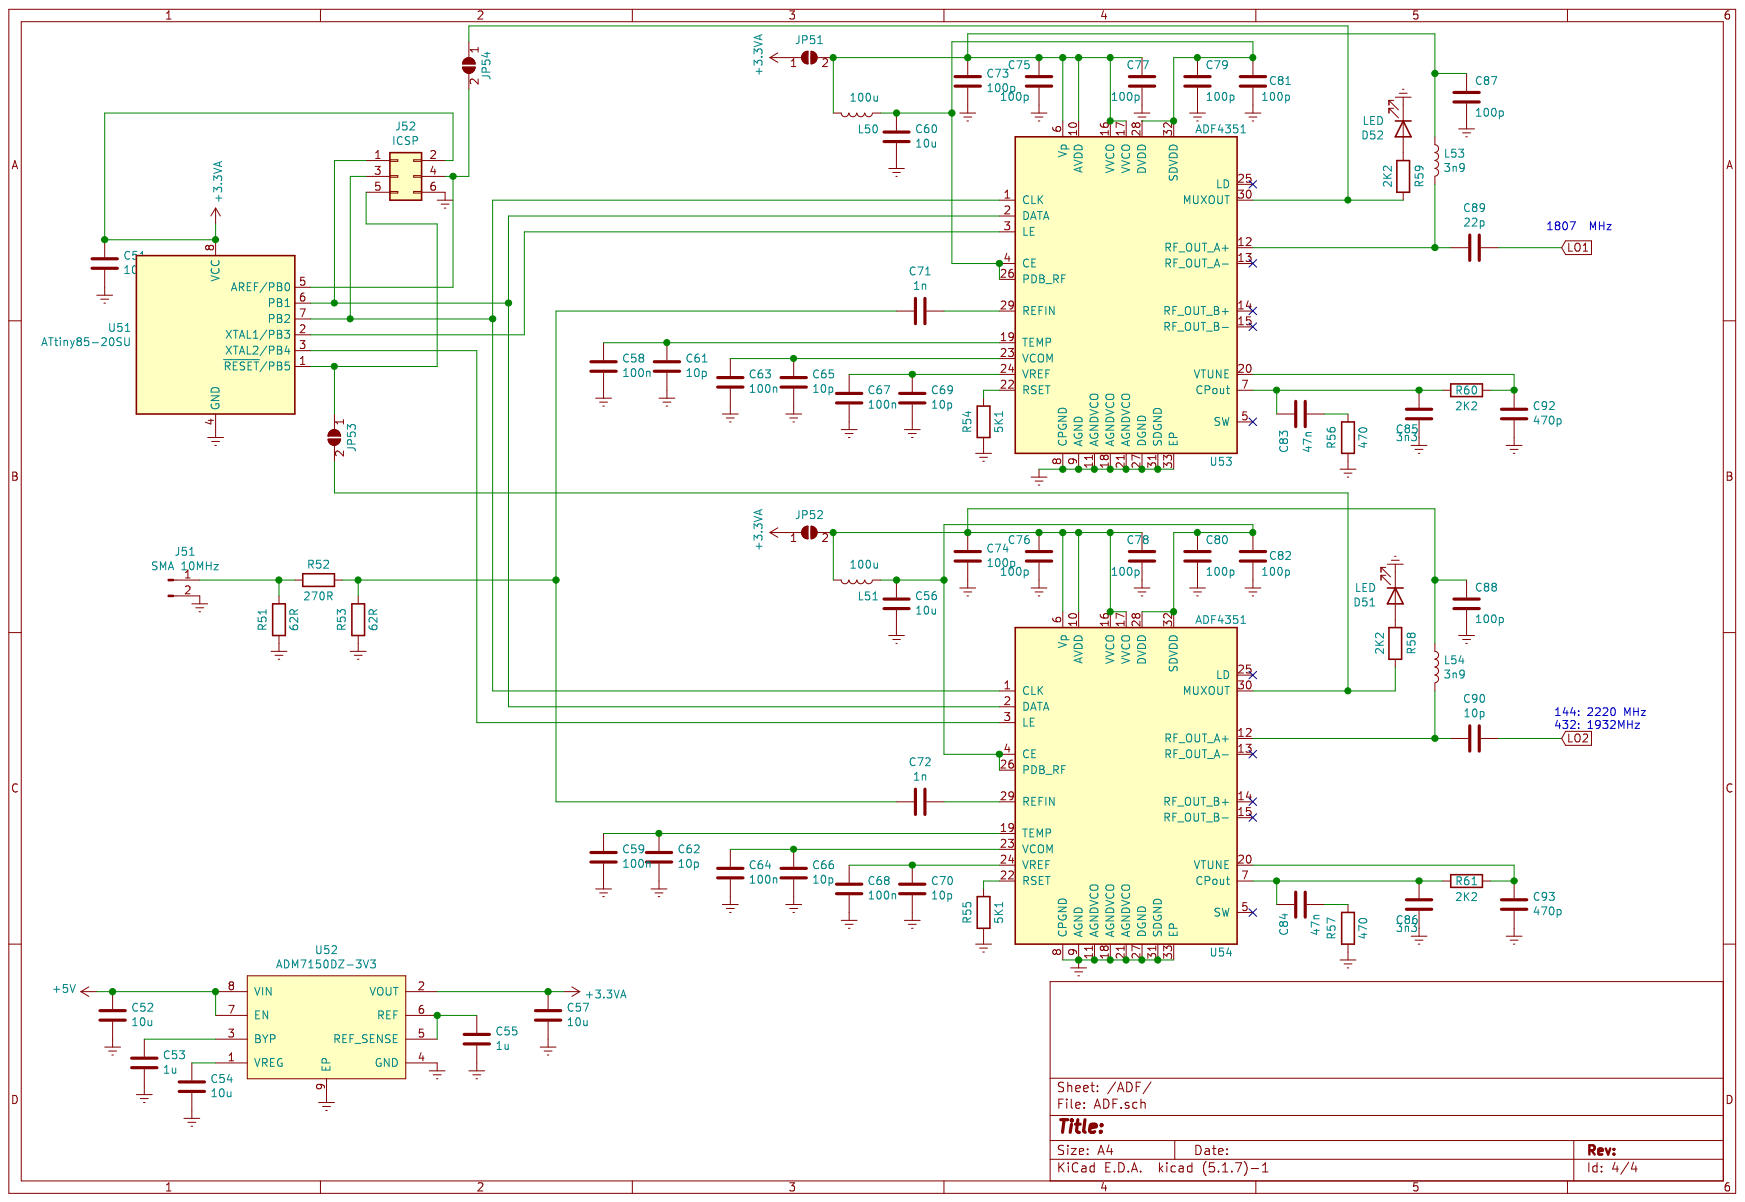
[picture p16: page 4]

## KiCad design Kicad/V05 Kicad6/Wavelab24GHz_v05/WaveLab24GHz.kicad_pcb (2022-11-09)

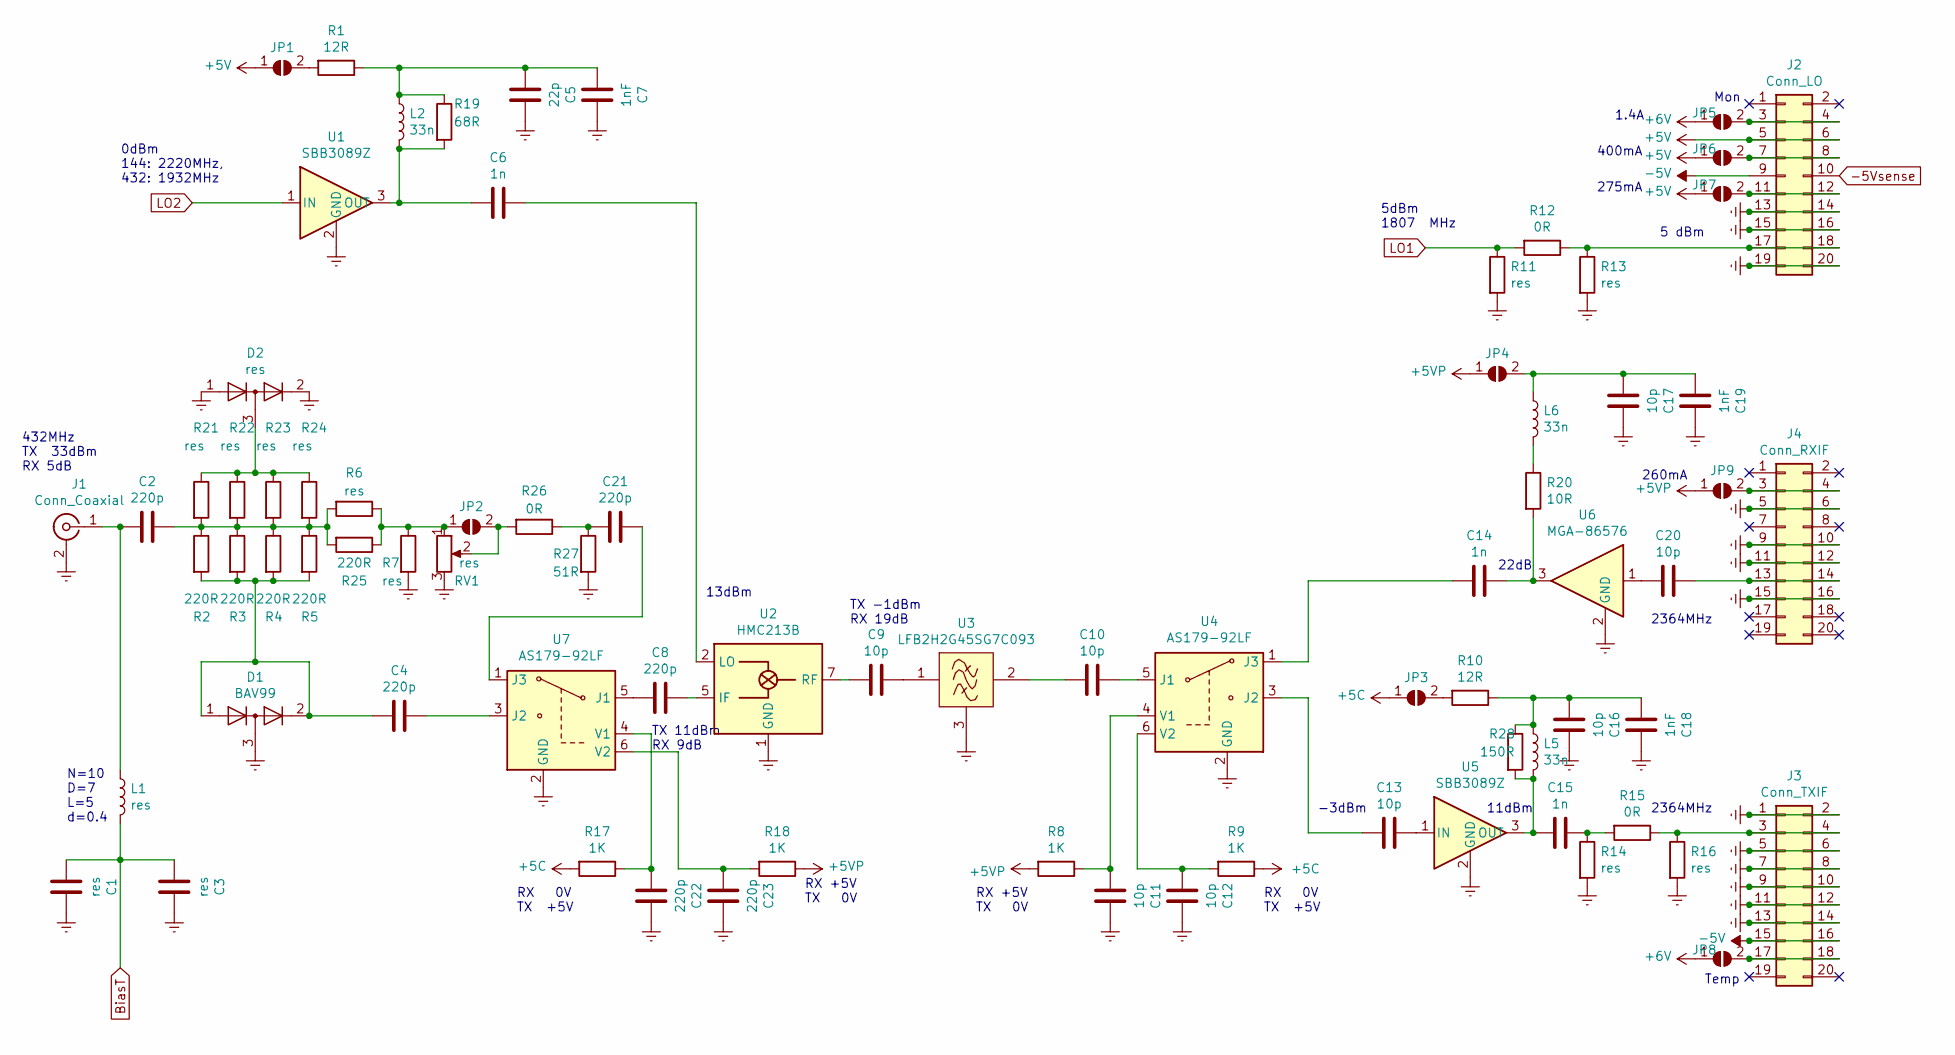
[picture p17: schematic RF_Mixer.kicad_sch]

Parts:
C1, C3: res; C_0805_2012Metric_Pad1.18x1.45mm_HandSolder
C2, C4, C8, C21, C22, C23: 220p; C_0805_2012Metric_Pad1.18x1.45mm_HandSolder
C5: 22p; C_0805_2012Metric_Pad1.18x1.45mm_HandSolder
C6, C14, C15: 1n; C_0805_2012Metric_Pad1.18x1.45mm_HandSolder
C7, C18, C19: 1nF; C_0805_2012Metric_Pad1.18x1.45mm_HandSolder
C9, C10, C11, C12, C13, C16, C17, C20: 10p; C_0805_2012Metric_Pad1.18x1.45mm_HandSolder
D1: BAV99; SOT-23
D2: res; SOT-23
J1: Conn_Coaxial; SMA_side_PCB
J2: Conn_LO; PinHeader_24GHz-NP
J3: Conn_TXIF; PinHeader_24GHz-NP
J4: Conn_RXIF; PinHeader_24GHz-NP
JP1, JP2, JP3, JP4, JP5, JP6, JP7, JP8, JP9: S; SolderJumper-2_P1.3mm_Open_RoundedPad1.0x1.5mm
L1: res; AirCoilSMD
L2, L5, L6: 33n; L_0805_2012Metric_Pad1.15x1.40mm_HandSolder
R1, R10: 12R; R_0805_2012Metric_Pad1.20x1.40mm_HandSolder
R2, R3, R4, R5, R25: 220R; R_1206_3216Metric_Pad1.30x1.75mm_HandSolder
R6, R21, R22, R23, R24: res; R_1206_3216Metric_Pad1.30x1.75mm_HandSolder
R7, R11, R13, R14, R16: res; R_0805_2012Metric_Pad1.20x1.40mm_HandSolder
R8, R17, R18: 1K; R_0805_2012Metric_Pad1.20x1.40mm_HandSolder
R9: 1K; R_1206_3216Metric_Pad1.30x1.75mm_HandSolder
R12: 0R; R_1206_3216Metric_Pad1.30x1.75mm_HandSolder
R15, R26: 0R; R_0805_2012Metric_Pad1.20x1.40mm_HandSolder
R19: 68R; R_0805_2012Metric_Pad1.20x1.40mm_HandSolder
R20: 10R; R_0805_2012Metric_Pad1.20x1.40mm_HandSolder
R27: 51R; R_0805_2012Metric_Pad1.20x1.40mm_HandSolder
R28: 150R; R_0805_2012Metric_Pad1.20x1.40mm_HandSolder
RV1: res; Potentiometer_Vishay_TS53YJ_Vertical
U1, U5: SBB3089Z; SOT-89-3
U2: HMC213B; MSOP-8_3x3mm_P0.65mm
U3: LFB2H2G45SG7C093; LFSN25N
U4, U7: AS179-92LF; SOT-363_SC-70-6
U6: MGA-86576

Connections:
+5C: JP3.1 (A), R9.1, R17.2; also elsewhere on the board
+5V: J2.5, J2.6, JP1.1 (A), JP6.1 (A), JP7.1 (A); also elsewhere on the board
+6V: JP5.1 (A), JP8.1 (A); also elsewhere on the board
-5V: J2.9, J3.15, J3.16; also elsewhere on the board
-5Vsense: J2.10; also elsewhere on the board
BiasT: C1.2, C3.2, L1.2; also elsewhere on the board
GNDREF: C1.1, C3.1, C5.1, C7.1, C11.1, C12.1, C16.1, C17.1, C18.1, C19.1, C22.1, C23.1, D1.3 (K), D2.1 (K), D2.2 (A), J1.2 (Ext), J2.13, J2.14, J2.15, J2.16, J2.19, J2.20, J3.1, J3.2, J3.5, J3.6, J3.7, J3.8, J3.9, J3.10, J3.11, J3.12, J3.13, J3.14, J4.5, J4.6, J4.9, J4.10, J4.11, J4.12, J4.15, J4.16, R7.2, R11.2, R13.2, R14.2, R16.2, R27.2, RV1.3, U1.2 (GND), U2.1 (GND), U2.3 (GND), U2.6 (GND), U2.8 (GND), U3.3, U3.4, U4.2 (GND), U5.2 (GND), U6.2 (GND), U7.2 (GND); also elsewhere on the board
LO1: R11.1, R12.2; also elsewhere on the board
LO2: U1.1 (IN); also elsewhere on the board
unnamed: C2.1, R2.1, R3.1, R4.1, R5.1, R6.2, R21.2, R22.2, R23.2, R24.2, R25.2
unnamed: C2.2, J1.1 (In), L1.1
unnamed: C4.1, U7.3 (J2)
unnamed: C4.2, D1.1 (K), D1.2 (A), R2.2, R3.2, R4.2, R5.2
unnamed: C5.2, C7.2, L2.1, R1.1, R19.1
unnamed: C6.1, U2.2 (LO)
unnamed: C6.2, L2.2, R19.2, U1.3 (OUT)
unnamed: C8.1, U2.5 (IF)
unnamed: C8.2, U7.5 (J1)
unnamed: C9.1, U3.1
unnamed: C9.2, U2.7 (RF)
unnamed: C10.1, U4.5 (J1)
unnamed: C10.2, U3.2
unnamed: C11.2, R8.1, U4.4 (V1)
unnamed: C12.2, R9.2, U4.6 (V2)
unnamed: C13.1, U5.1 (IN)
unnamed: C13.2, U4.3 (J2)
unnamed: C14.1, R20.2, U6.3
unnamed: C14.2, U4.1 (J3)
unnamed: C15.1, R14.1, R15.2
unnamed: C15.2, L5.2, R28.2, U5.3 (OUT)
unnamed: C16.2, C18.2, L5.1, R10.1, R28.1
unnamed: C17.2, C19.2, JP4.2 (B), L6.1
unnamed: C20.1, J4.13, J4.14
unnamed: C20.2, U6.1
unnamed: C21.1, U7.1 (J3)
unnamed: C21.2, R26.1, R27.1
unnamed: C22.2, R17.1, U7.4 (V1)
unnamed: C23.2, R18.2, U7.6 (V2)
unnamed: D2.3 (K), R21.1, R22.1, R23.1, R24.1
unnamed: J2.3, J2.4, JP5.2 (B)
unnamed: J2.7, J2.8, JP6.2 (B)
unnamed: J2.11, J2.12, JP7.2 (B)
unnamed: J2.17, J2.18, R12.1, R13.1
unnamed: J3.3, J3.4, R15.1, R16.1
unnamed: J3.17, J3.18, JP8.2 (B)
unnamed: J4.3, J4.4, JP9.2 (B)
unnamed: JP1.2 (B), R1.2
unnamed: JP2.1 (A), R6.1, R7.1, R25.1, RV1.1
unnamed: JP2.2 (B), R26.2, RV1.2
unnamed: JP3.2 (B), R10.2
unnamed: L6.2, R20.1

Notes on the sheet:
TX 11dBm RX 9dB
260mA
Temp
RX +5V TX 0V
275mA
11dBm
-3dBm
432MHz TX 33dBm RX 5dB
22dB
TX -1dBm RX 19dB
1.4A
N=10 D=7 L=5 d=0.4
0dBm 144: 2220MHz, 432: 1932MHz
2364MHz
RX 0V TX +5V
Mon
400mA
13dBm
2364MHz
5 dBm
5dBm 1807 MHz

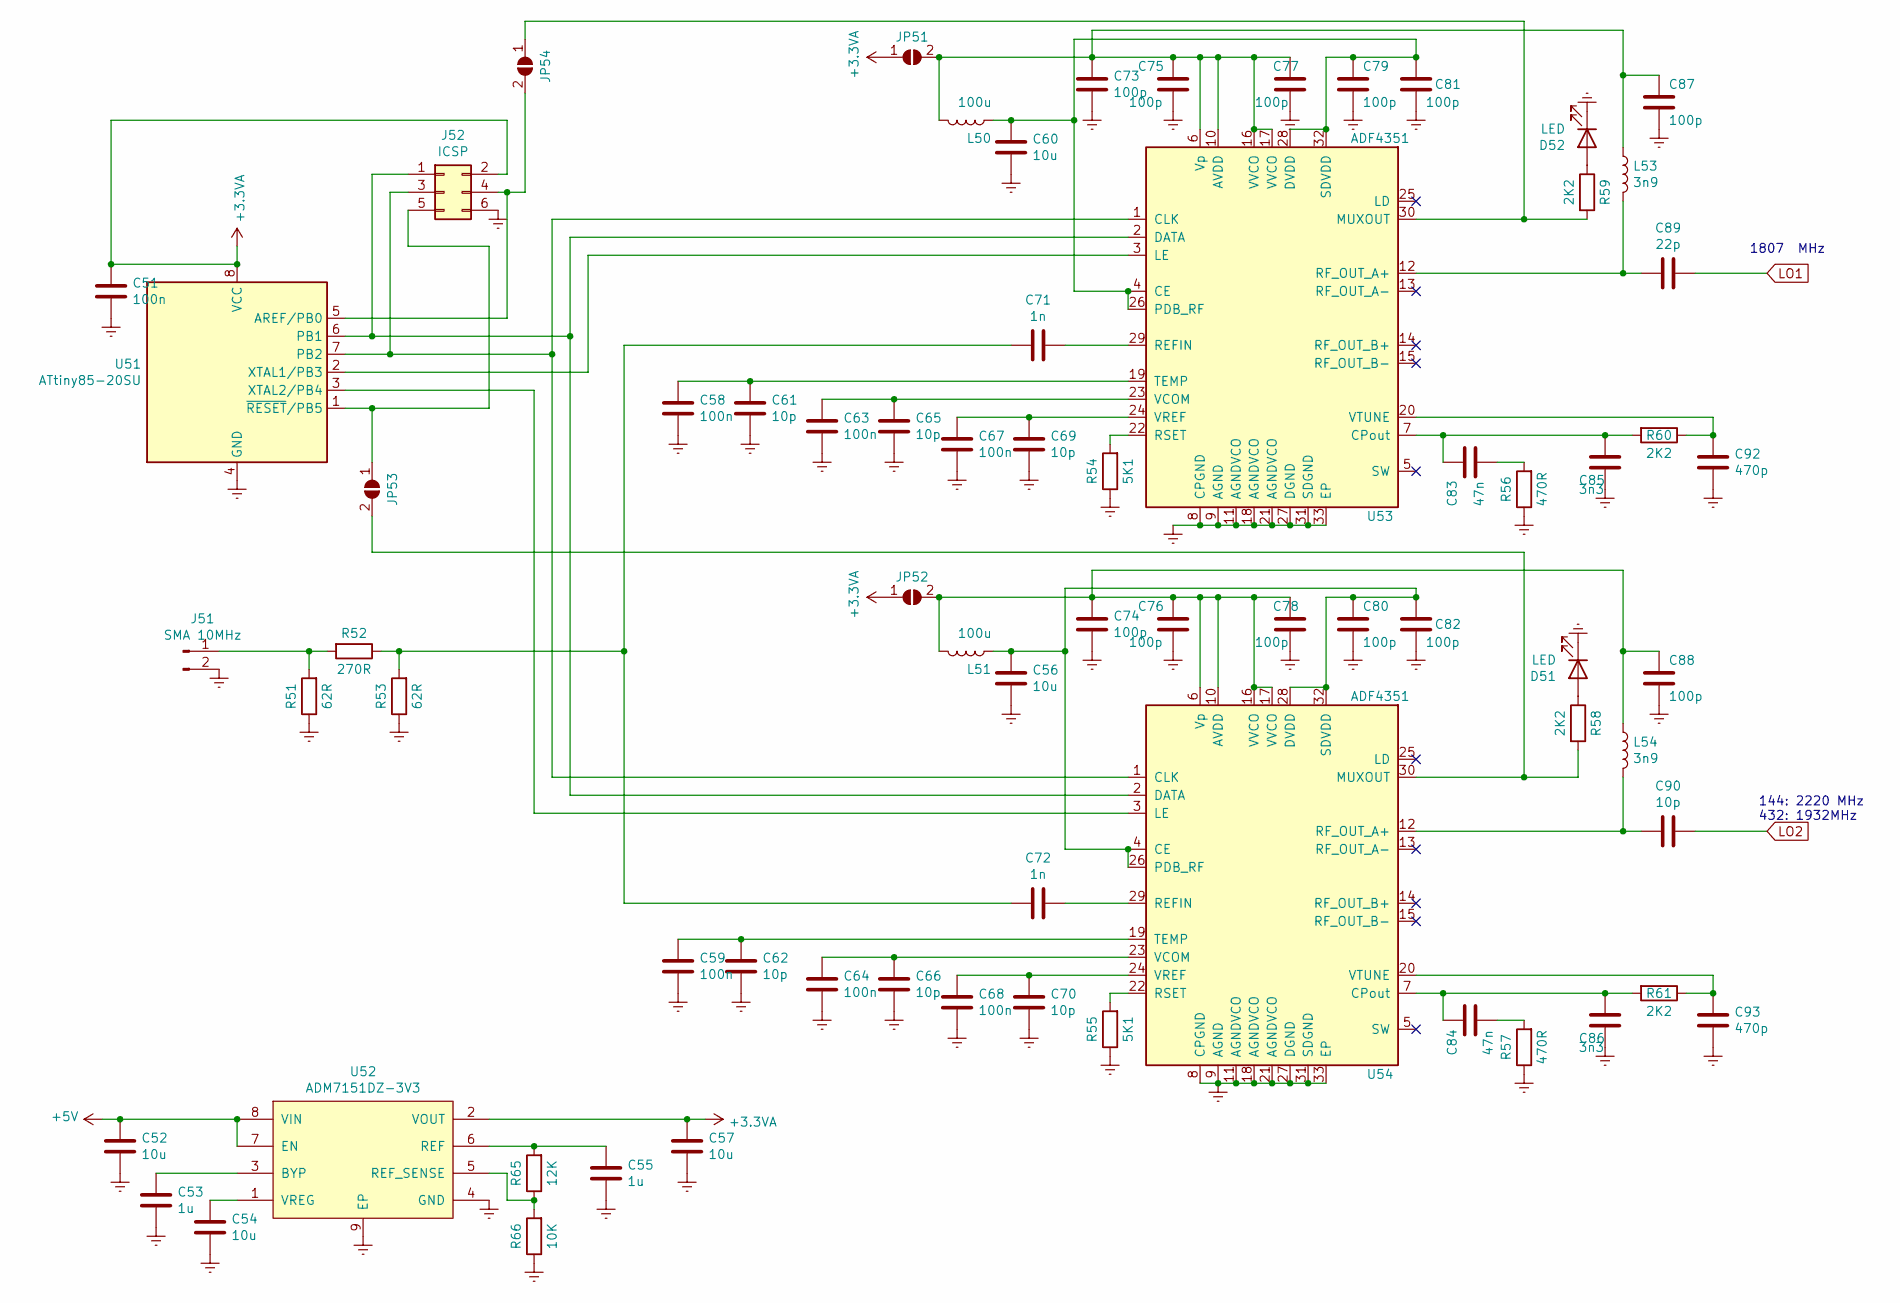
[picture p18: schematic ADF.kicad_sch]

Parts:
C51, C58, C59, C63, C64, C67, C68: 100n; C_0805_2012Metric_Pad1.18x1.45mm_HandSolder
C52, C54, C56, C57, C60: 10u; C_0805_2012Metric_Pad1.18x1.45mm_HandSolder
C53, C55: 1u; C_0805_2012Metric_Pad1.18x1.45mm_HandSolder
C61, C62, C65, C66, C69, C70: 10p; C_0603_1608Metric_Pad1.08x0.95mm_HandSolder
C71, C72: 1n; C_0805_2012Metric_Pad1.18x1.45mm_HandSolder
C73, C74, C75, C76, C77, C78, C79, C80, C81, C82: 100p; C_0603_1608Metric_Pad1.08x0.95mm_HandSolder
C83, C84: 47n; C_0805_2012Metric_Pad1.18x1.45mm_HandSolder
C85, C86: 3n3; C_0805_2012Metric_Pad1.18x1.45mm_HandSolder
C87, C88: 100p; C_0805_2012Metric_Pad1.18x1.45mm_HandSolder
C89: 22p; C_0805_2012Metric_Pad1.18x1.45mm_HandSolder
C90: 10p; C_0805_2012Metric_Pad1.18x1.45mm_HandSolder
C92, C93: 470p; C_0805_2012Metric_Pad1.18x1.45mm_HandSolder
D51, D52: LED; LED_0805_2012Metric_Pad1.15x1.40mm_HandSolder
J51: SMA 10MHz; SMA_side_PCB
J52: ICSP; IDC-Header_2x03_P2.54mm_SMD
JP51, JP52, JP53, JP54: S; SolderJumper-2_P1.3mm_Open_RoundedPad1.0x1.5mm
L50, L51: 100u; L_0805_2012Metric_Pad1.05x1.20mm_HandSolder
L53, L54: 3n9; L_0805_2012Metric_Pad1.05x1.20mm_HandSolder
R51, R53: 62R; R_0805_2012Metric_Pad1.20x1.40mm_HandSolder
R52: 270R; R_0805_2012Metric_Pad1.20x1.40mm_HandSolder
R54, R55: 5K1; R_0805_2012Metric_Pad1.20x1.40mm_HandSolder
R56, R57: 470R; R_0805_2012Metric_Pad1.20x1.40mm_HandSolder
R58, R59, R60, R61: 2K2; R_0805_2012Metric_Pad1.20x1.40mm_HandSolder
R65: 12K; R_0805_2012Metric_Pad1.20x1.40mm_HandSolder
R66: 10K; R_0805_2012Metric_Pad1.20x1.40mm_HandSolder
U51: ATtiny85-20SU; SOIJ-8_5.3x5.3mm_P1.27mm
U52: ADM7151DZ-3V3; SOIC-8-1EP_3.9x4.9mm_P1.27mm_EP2.29x3mm_ThermalVias
U53, U54: ADF4351; LFCSP-32-1EP_5x5mm_P0.5mm_EP3.1x3.1mm_ThermalVias

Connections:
+3.3VA: C51.2, C57.2, J52.2, JP51.1 (A), JP52.1 (A), U51.8 (VCC), U52.2 (VOUT)
+5V: C52.2, U52.7 (EN), U52.8 (VIN); also elsewhere on the board
GNDREF: C51.1, C52.1, C53.1, C54.1, C55.1, C56.1, C57.1, C58.1, C59.1, C60.1, C61.1, C62.1, C63.1, C64.1, C65.1, C66.1, C67.1, C68.1, C69.1, C70.1, C73.1, C74.1, C75.1, C76.1, C77.1, C78.1, C79.1, C80.1, C81.1, C82.1, C85.1, C86.1, C87.1, C88.1, C92.1, C93.1, D51.1 (K), D52.1 (K), J51.2, J52.6, R51.1, R53.1, R54.1, R55.1, R56.1, R57.1, R66.1, U51.4 (GND), U52.4 (GND), U52.9 (EP), U53.8 (CPGND), U53.9 (AGND), U53.11 (AGNDVCO), U53.18 (AGNDVCO), U53.21 (AGNDVCO), U53.27 (DGND), U53.31 (SDGND), U53.33 (EP), U54.8 (CPGND), U54.9 (AGND), U54.11 (AGNDVCO), U54.18 (AGNDVCO), U54.21 (AGNDVCO), U54.27 (DGND), U54.31 (SDGND), U54.33 (EP); also elsewhere on the board
LO1: C89.1; also elsewhere on the board
LO2: C90.1; also elsewhere on the board
unnamed: C53.2, U52.3 (BYP)
unnamed: C54.2, U52.1 (VREG)
unnamed: C55.2, R65.2, U52.6 (REF)
unnamed: C56.2, C80.2, C82.2, L51.1, U54.4 (CE), U54.26 (PDB_RF), U54.28 (DVDD), U54.32 (SDVDD)
unnamed: C58.2, C61.2, U53.19 (TEMP)
unnamed: C59.2, C62.2, U54.19 (TEMP)
unnamed: C60.2, C79.2, C81.2, L50.1, U53.4 (CE), U53.26 (PDB_RF), U53.28 (DVDD), U53.32 (SDVDD)
unnamed: C63.2, C65.2, U53.23 (VCOM)
unnamed: C64.2, C66.2, U54.23 (VCOM)
unnamed: C67.2, C69.2, U53.24 (VREF)
unnamed: C68.2, C70.2, U54.24 (VREF)
unnamed: C71.1, U53.29 (REFIN)
unnamed: C71.2, C72.2, R52.1, R53.2
unnamed: C72.1, U54.29 (REFIN)
unnamed: C73.2, C75.2, C77.2, C87.2, JP51.2 (B), L50.2, L53.1, U53.6 (Vp), U53.10 (AVDD), U53.16 (VVCO), U53.17 (VVCO)
unnamed: C74.2, C76.2, C78.2, C88.2, JP52.2 (B), L51.2, L54.1, U54.6 (Vp), U54.10 (AVDD), U54.16 (VVCO), U54.17 (VVCO)
unnamed: C83.1, R56.2
unnamed: C83.2, C85.2, R60.2, U53.7 (CPout)
unnamed: C84.1, R57.2
unnamed: C84.2, C86.2, R61.2, U54.7 (CPout)
unnamed: C89.2, L53.2, U53.12 (RF_OUT_A+)
unnamed: C90.2, L54.2, U54.12 (RF_OUT_A+)
unnamed: C92.2, R60.1, U53.20 (VTUNE)
unnamed: C93.2, R61.1, U54.20 (VTUNE)
unnamed: D51.2 (A), R58.1
unnamed: D52.2 (A), R59.1
unnamed: J51.1, R51.2, R52.2
unnamed: J52.1, U51.6 (PB1), U53.2 (DATA), U54.2 (DATA)
unnamed: J52.3, U51.7 (PB2), U53.1 (CLK), U54.1 (CLK)
unnamed: J52.4, JP54.2 (B), U51.5 (AREF/PB0)
unnamed: J52.5, JP53.1 (A), U51.1 (~RESET/PB5)
unnamed: JP53.2 (B), R58.2, U54.30 (MUXOUT)
unnamed: JP54.1 (A), R59.2, U53.30 (MUXOUT)
unnamed: R54.2, U53.22 (RSET)
unnamed: R55.2, U54.22 (RSET)
unnamed: R65.1, R66.2, U52.5 (REF_SENSE)
unnamed: U51.2 (XTAL1/PB3), U53.3 (LE)
unnamed: U51.3 (XTAL2/PB4), U54.3 (LE)

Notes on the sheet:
1807 MHz
144: 2220 MHz 432: 1932MHz

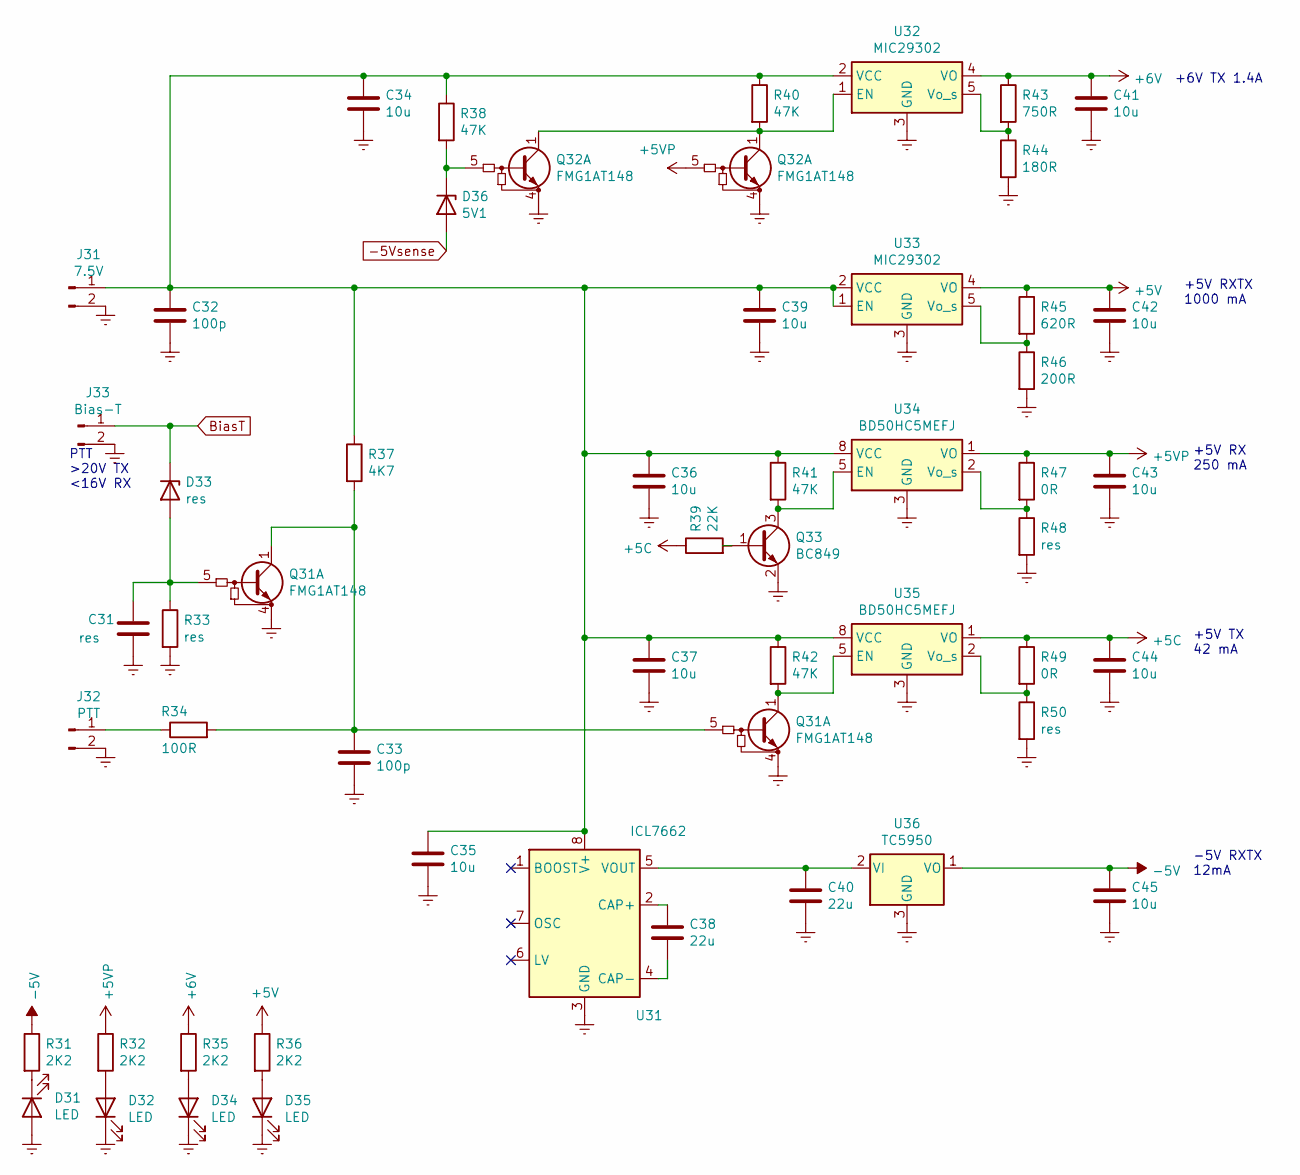
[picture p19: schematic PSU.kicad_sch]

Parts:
C31: res; C_0805_2012Metric_Pad1.18x1.45mm_HandSolder
C32, C33: 100p; C_0805_2012Metric_Pad1.18x1.45mm_HandSolder
C34, C35, C36, C37, C39, C41, C42, C43, C44, C45: 10u; C_0805_2012Metric_Pad1.18x1.45mm_HandSolder
C38, C40: 22u; C_0805_2012Metric_Pad1.18x1.45mm_HandSolder
D31, D32, D34, D35: LED; LED_0805_2012Metric_Pad1.15x1.40mm_HandSolder
D33: res; R_0805_2012Metric_Pad1.20x1.40mm_HandSolder
D36: 5V1; R_0805_2012Metric_Pad1.20x1.40mm_HandSolder
J31: 7.5V; KF301-2P-NP
J32: PTT; KF301-2P-NP
J33: Bias-T; KF301-2P-NP
Q31, Q32: FMG1AT148; SOT-25_HandSoldering
Q33: BC849; SOT-23
R31, R32, R35, R36: 2K2; R_0805_2012Metric_Pad1.20x1.40mm_HandSolder
R33, R48, R50: res; R_0805_2012Metric_Pad1.20x1.40mm_HandSolder
R34: 100R; R_0805_2012Metric_Pad1.20x1.40mm_HandSolder
R37: 4K7; R_0805_2012Metric_Pad1.20x1.40mm_HandSolder
R38, R40, R41, R42: 47K; R_0805_2012Metric_Pad1.20x1.40mm_HandSolder
R39: 22K; R_0805_2012Metric_Pad1.20x1.40mm_HandSolder
R43: 750R; R_0805_2012Metric_Pad1.20x1.40mm_HandSolder
R44: 180R; R_0805_2012Metric_Pad1.20x1.40mm_HandSolder
R45: 620R; R_0805_2012Metric_Pad1.20x1.40mm_HandSolder
R46: 200R; R_0805_2012Metric_Pad1.20x1.40mm_HandSolder
R47, R49: 0R; R_0805_2012Metric_Pad1.20x1.40mm_HandSolder
U31: ICL7662; SOIC-8_3.9x4.9mm_P1.27mm
U32, U33: MIC29302; TO-263-5_TabPin6
U34, U35: BD50HC5MEFJ; HTSOP-8-1EP_3.9x4.9mm_P1.27mm_EP2.4x3.2mm
U36: TC5950; SOT-23

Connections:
+5C: C44.1, R39.1, R49.1, U35.1 (VO); also elsewhere on the board
+5V: C42.1, R36.1, R45.1, U33.4 (VO); also elsewhere on the board
+6V: C41.1, R35.1, R43.1, U32.4 (VO); also elsewhere on the board
-5V: C45.1, R31.1, U36.1 (VO); also elsewhere on the board
-5Vsense: D36.2 (A); also elsewhere on the board
BiasT: D33.1 (K), J33.1; also elsewhere on the board
GNDREF: C31.2, C32.2, C33.2, C34.2, C35.2, C36.2, C37.2, C39.2, C40.2, C41.2, C42.2, C43.2, C44.2, C45.2, D31.2 (A), D32.1 (K), D34.1 (K), D35.1 (K), J31.2, J32.2, J33.2, Q31.4 (E1), Q32.4 (E1), Q33.2 (E), R33.2, R44.2, R46.2, R48.2, R50.2, U31.3 (GND), U32.3 (GND), U32.6 (GND), U33.3 (GND), U33.6 (GND), U34.3 (GND), U34.4 (GND), U34.6 (GND), U34.7 (GND), U34.9 (GND), U35.3 (GND), U35.4 (GND), U35.6 (GND), U35.7 (GND), U35.9 (GND), U36.3 (GND); also elsewhere on the board
unnamed: C32.1, C34.1, C35.1, C36.1, C37.1, C39.1, J31.1, R37.1, R38.1, R40.1, R41.1, R42.1, U31.8 (V+), U32.2 (VCC), U33.1 (EN), U33.2 (VCC), U34.8 (VCC), U35.8 (VCC)
unnamed: C38.1, U31.2 (CAP+)
unnamed: C38.2, U31.4 (CAP-)
unnamed: C40.1, U31.5 (VOUT), U36.2 (VI)
unnamed: D31.1 (K), R31.2
unnamed: D32.2 (A), R32.2
unnamed: D34.2 (A), R35.2
unnamed: D35.2 (A), R36.2
unnamed: J32.1, R34.1
unnamed: Q32.1 (C1), Q32.2 (C1), R40.2, U32.1 (EN)
unnamed: Q33.1 (B), R39.2
unnamed: Q33.3 (C), R41.2, U34.5 (EN)
unnamed: R43.2, R44.1, U32.5 (Vo_s)
unnamed: R45.2, R46.1, U33.5 (Vo_s)
unnamed: R47.2, R48.1, U34.2 (Vo_s)
unnamed: R49.2, R50.1, U35.2 (Vo_s)

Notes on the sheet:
+6V TX 1.4A
+5V RX 250 mA
+5V RXTX 1000 mA
PTT >20V TX <16V RX
+5V TX 42 mA
-5V RXTX 12mA

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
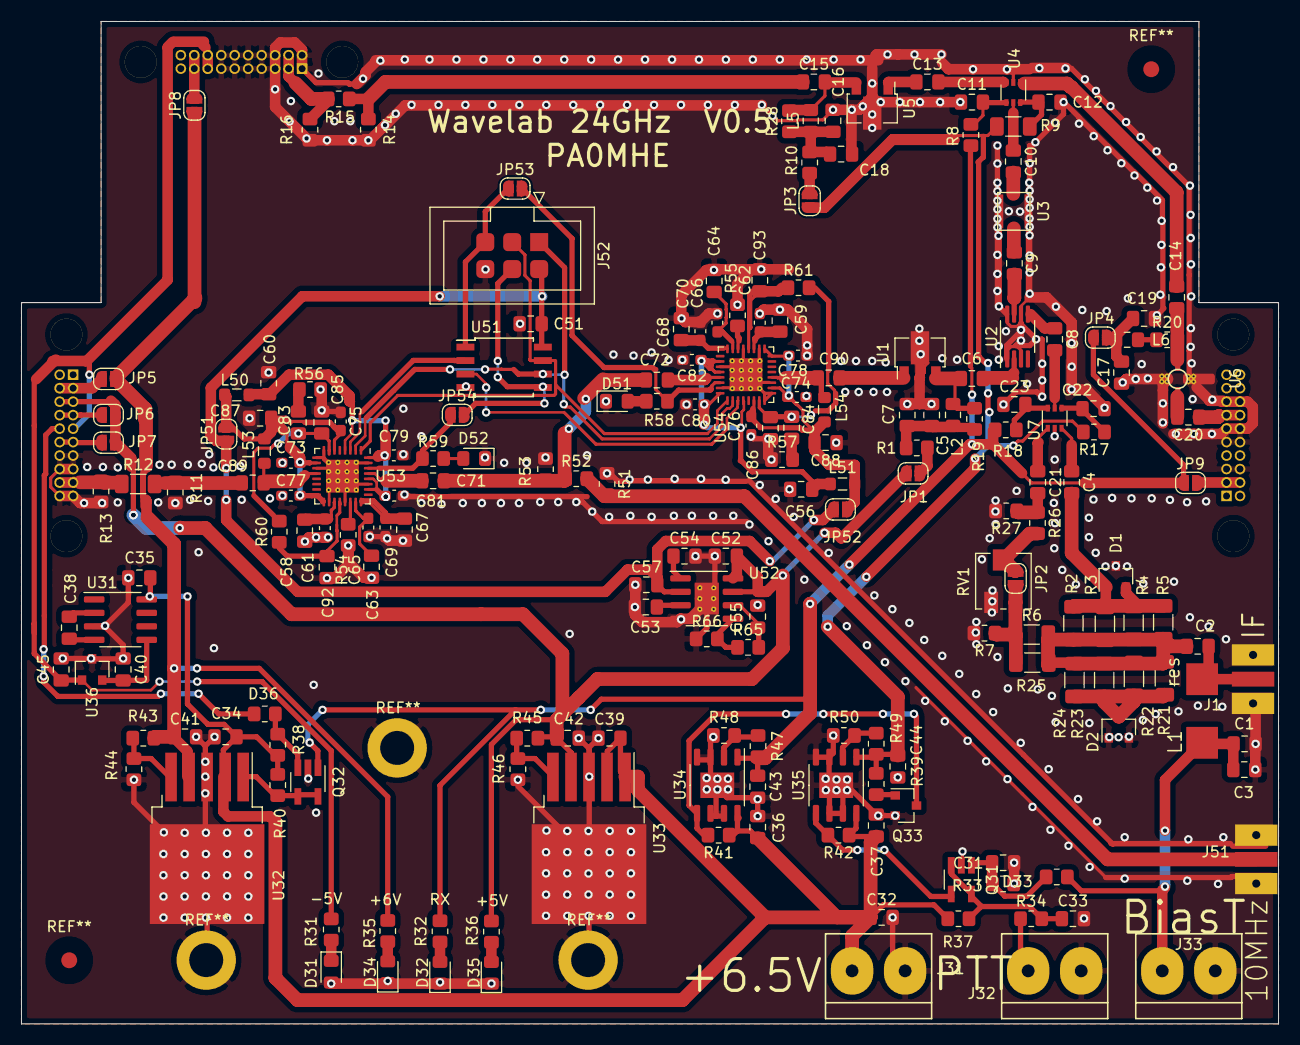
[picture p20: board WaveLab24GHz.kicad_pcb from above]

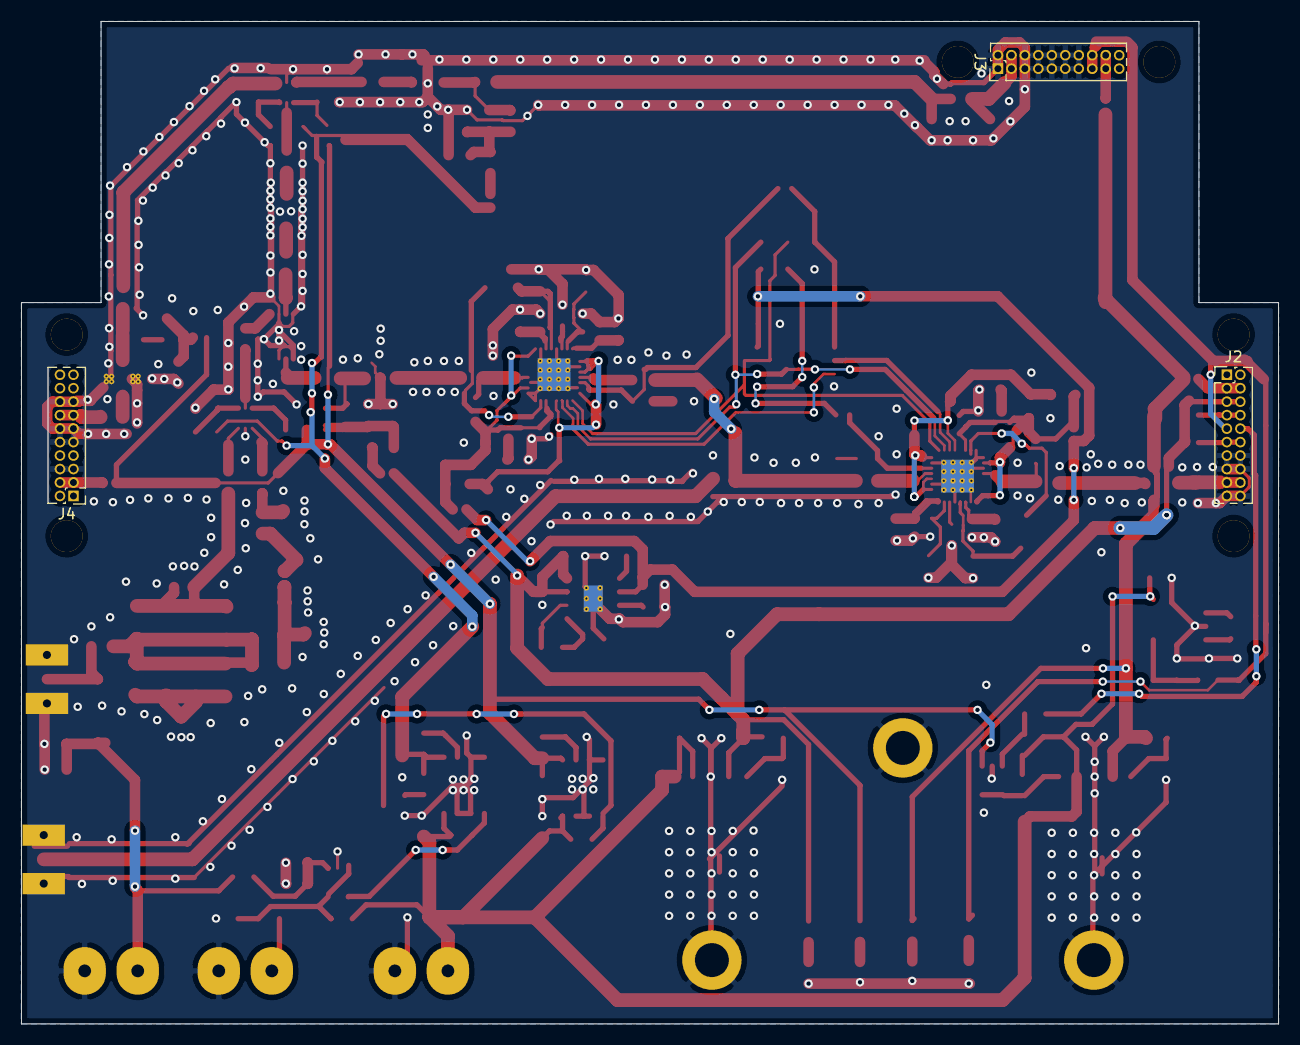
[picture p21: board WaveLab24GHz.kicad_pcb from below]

Board: 2 copper layers, 118.5 x 94.5 mm, 202 parts (3 on the bottom side), 111 nets.

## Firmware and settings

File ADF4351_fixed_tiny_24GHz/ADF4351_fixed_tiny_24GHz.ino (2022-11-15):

//  By Maarten PA0MHE 02-01-2022
//******************************************** HARDWARE ********************************************************
//  For ATTINY85 with dual ADF4351:
//  PB0   pin 5   ADF1 MUXout(must be disconnected during programming) No SW to detect yet
//  PB1   pin 6   ADF DAT
//  PB2   pin 7   ADF CLK
//  PB3   pin 2   ADF1 LE (1806 MHz) 
//  PB4   pin 3   ADF2 LE (2220 MHz)
//  PB5   pin 1   ADF2 MUXout (must be disconnected during programming) No SW to detect yet
// 
//  Set the system clock to 1MHz internal.
//******************************************************************************************************************

#include <tinySPI.h>                     // https://github.com/JChristensen/tinySPI

#define ADF1_MUX DDB0
#define ADF1_LE DDB3                     // PIN2 storage register
#define ADF2_MUX DDB5
#define ADF2_LE DDB4                     // PIN3 storage register
#define CLK DDB2
#define DAT DDB1 

uint32_t reg1[6] =  {0x5A0038, 0x8008051, 0x1A004E42, 0x4B3, 0x9A003C, 0x580005} ; // 1807MHz, ref 10MHz x2, 5dBm, Muxout: digital lock detect
//uint32_t reg1[6] =  {0x5A8048, 0x8008051, 0x1A004E42, 0x4B3, 0x9A003C, 0x580005} ; // 1819MHz, ref 10MHz x2, 5dBm, Muxout: digital lock detect
//uint32_t reg2[6] =  {0x378000, 0x8008011, 0x1A004E42, 0x4B3, 0x8A003C, 0x580005} ; // 2m, 2220MHz, ref 10MHz x2, 5dBm, Muxout: digital lock detect
//uint32_t reg2[6] =  { 0x600018, 0x8008029, 0x1A004E42, 0x4B3, 0x9A003C, 0x580005 } ; //438MHz, 1926MHz, ref 10MHz x2, 5dBm, Muxout: digital lock detect 
uint32_t reg2[6] =  {0x608008, 0x8008029, 0x1A004E42, 0x4B3, 0x9A003C, 0x580005} ; // 70cm, 1932MHz, ref 10MHz x2, 5dBm, Muxout: digital lock detect

void setup() {
  SPI.begin();                            // Init SPI bus
  pinMode(ADF1_LE, OUTPUT);               // latch pin needs to be set up
  pinMode(ADF2_LE, OUTPUT);              
  digitalWrite(ADF1_LE, HIGH);
  digitalWrite(ADF2_LE, HIGH);
  pinMode(ADF1_MUX, INPUT);
  pinMode(ADF2_MUX, INPUT);

  delay(1000);                            // Give ADF4351 time to setup

  ADFSet(reg1, ADF1_LE);
  delay(500);
  ADFSet(reg2, ADF2_LE);
  }


void loop(){

} 


void ADFSet(uint32_t reg[6], byte LE) {  // Program all 6 registers ADF4351 
  for (int i = 5; i >= 0; i--) {         // program ADF4351 start with R5
    ADFWriteRegister32(reg[i], LE);
  } 
  delay(1);
  ADFWriteRegister32(reg[0], LE);        // Program R0 again
}


void ADFWriteRegister32(const uint32_t value, byte LE) //Program data into one of the 32bits register, the register that is selected by the four LSBs.
{
  digitalWrite(LE, LOW);
  for (int i = 3; i >= 0; i--)             // loop through 4 x 8bits
  SPI.transfer((value >> 8 * i) & 0xFF);   // shift , mask and send octet via SPI
  digitalWrite(LE, HIGH);                  // Load Enable rising edge the data stored in the shift register
  digitalWrite(LE, LOW);                   // 
}

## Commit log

2022-05-29 Updated schematic
2022-06-03 Added the Kicad project
    [ADF.sch, PSU.sch, RF_Mixer.sch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]
2022-06-04 Added own made footprints
2022-08-22 Create BOM_v04_2.xlsx
    Updated BOM
    [BOM_v04_2.xlsx]
2022-08-29 Added some alternative components
    [BOM_v04_2.xlsx]
2022-11-09 Added production files
    [ADF.kicad_sch, ADF.sch, PSU.kicad_sch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]
